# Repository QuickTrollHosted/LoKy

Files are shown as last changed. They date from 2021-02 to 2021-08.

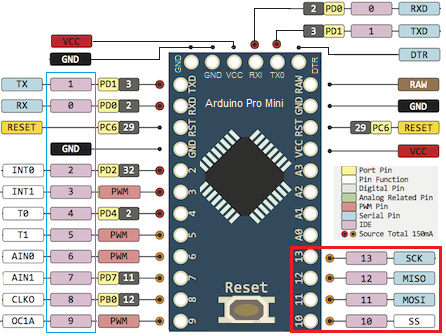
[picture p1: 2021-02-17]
LoKy_Documentation/Pin_Out/Pro_Mini.png

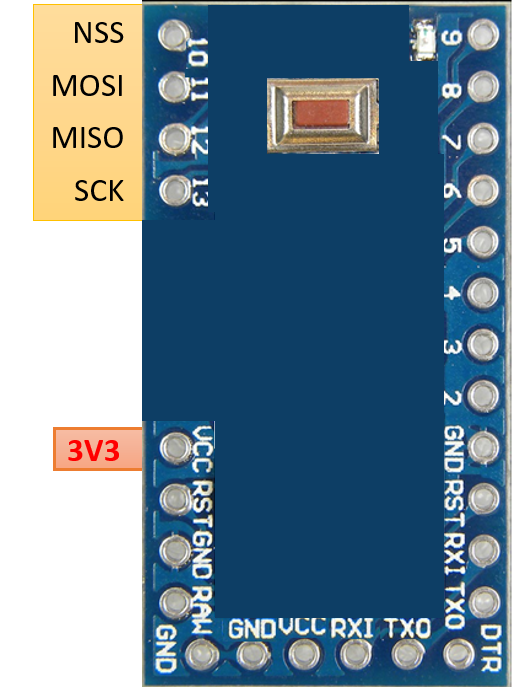
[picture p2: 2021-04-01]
LoKy_Documentation/Pin_Out/Pro_Mini_cut.png

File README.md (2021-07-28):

Shield: [][cc-by-nc-sa]

This work is licensed under a
[Creative Commons Attribution-NonCommercial-ShareAlike 4.0 International License][cc-by-nc-sa].

[][cc-by-nc-sa]

[cc-by-nc-sa]: http://creativecommons.org/licenses/by-nc-sa/4.0/
[cc-by-nc-sa-image]: https://licensebuttons.net/l/by-nc-sa/4.0/88x31.png
[cc-by-nc-sa-shield]: https://img.shields.io/badge/License-CC%20BY--NC--SA%204.0-lightgrey.svg

# LoKy

- LoKy is an Open-source project which creates a LoRaWAN end-device to connect with Linky meter in France. 
- The most recent firmware is V4

This End-device was created by Ferrari Jérôme and Ho Vu Duy Bao for CNRS/UGA/G-INP – G2ELAB

CNRS-logo
G2elab-logo
UGA-logo
GINP-logo

[GINP-logo]: https://www.grenoble-inp.fr/uas/alias1/LOGO/Grenoble+INP+-+%C3%89tablissement+%28couleur%2C+RVB%2C+120px%29.png
[CNRS-logo]: https://www.cnrs.fr/themes/custom/cnrs/logo.svg
[G2elab-logo]: https://g2elab.grenoble-inp.fr/uas/alias31/LOGO/G2Elab-logo.jpg
[UGA-logo]:https://encrypted-tbn0.gstatic.com/images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

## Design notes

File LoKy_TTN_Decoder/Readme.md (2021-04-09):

# LoKy_LPP Introduction

LoKyLPP is a payload format modified by HO Vu Duy Bao from IoT platform [Cayenne](https://mydevices.com/cayenne/features/).
It is used to send electrical data in a packed format to [The Things Network](https://www.thethingsnetwork.org).

## Dependencies
When using the decoder, you must install the [ArduinoJson 6.X](https://arduinojson.org/) library. You can find it in both the Arduino IDE and PlatformIO library managers.

## References
* [Cayenne Low Power Payload](https://mydevices.com/cayenne/docs/#lora-cayenne-low-power-payload)
* [IPSO data types](http://openmobilealliance.org/wp/OMNA/LwM2M/LwM2MRegistry.html#extlabel)

## License
Based in the work of [Johan Stokking](https://github.com/TheThingsNetwork/arduino-device-lib).
The MIT License (MIT)

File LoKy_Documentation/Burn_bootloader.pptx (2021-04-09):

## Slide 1

PART 1 - The prepare schematic
Voltage supply is 3,3 volts. This supply has to be well regulated with no voltage spikes and an extra 10uF capacitor between 3V3 and GND. Also, the reset pin is negative enabled. In order to disable it, we need to apply 3V3 to it.
To reset, a 10k Ohms resistor is needed between RESET and Vcc.
In this tutorial, ATMega328P works at 3V3. For that, between pins 9 and 10 we place a 8MHz crystal. But this crystal, in order to oscillate needs two capacitors of 22pF connected to GND. In the figure above, you have all the pins of the chip. Right now, if the microcontroller has a bootloader, we could upload a code. But let's imagine it doesn't have a bootloader.

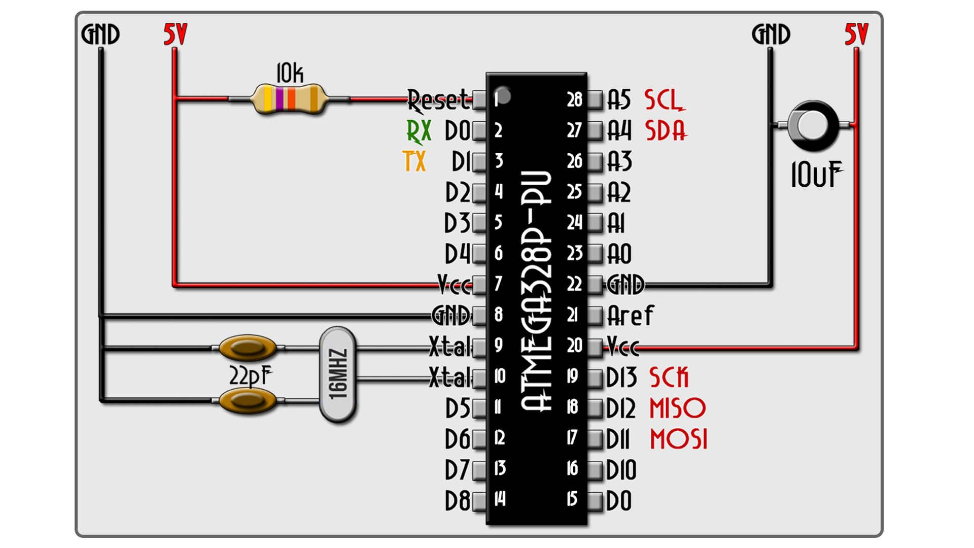
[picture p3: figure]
arduino on breadboard schematic

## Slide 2

PART 2 - Burn Bootloader
Now, if the chip doesn't have the bootloader (brand new chip), you have to make next connections from an Arduino ProMini. These are the SPI pins, CLOCK, MISO and MOSI.
Now connect the Arduino to your PC. Open Arduino IDE and go to File → Examples → Arduino ISP and upload that example. It’s time to burn the bootloader. Go to Tools → Programmer → Arduino as ISP. By that we change the programmer to ISP. Finally, go to Tools → Burn bootloader. Now the LEDs of the Arduino will blink a lot. Once you get the message of bootloader burned we are good to go.

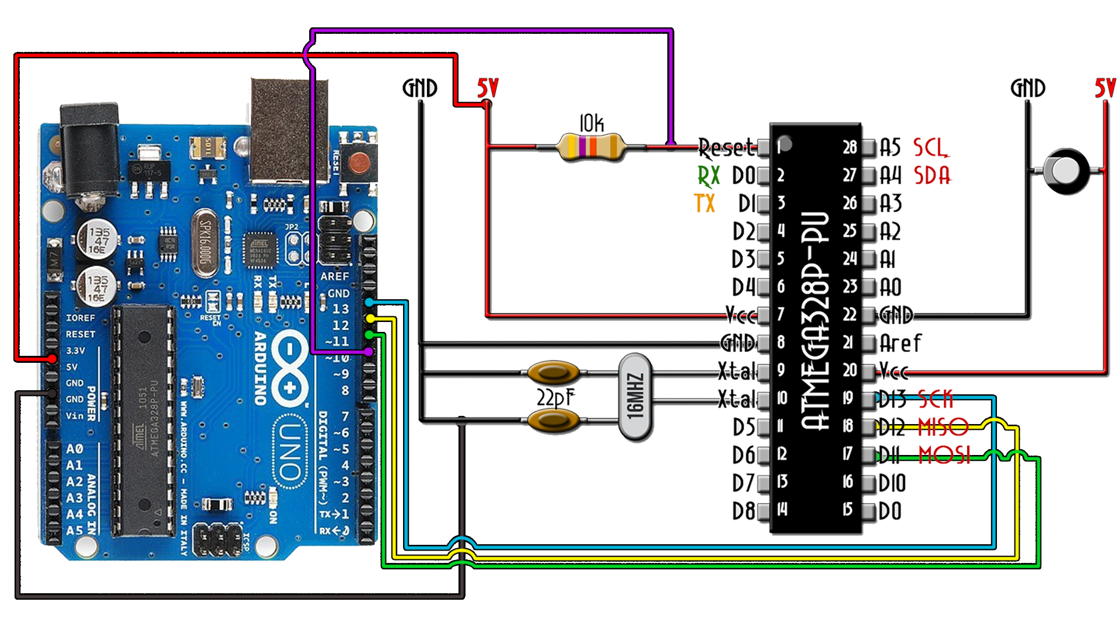
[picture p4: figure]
arduino on breadboard schematic

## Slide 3

PART 3 - Upload a code
Now, we have the bootloader so we can communicate with the RX and TX pins and upload a code. For that we need and FTDI module. Make the next connections and upload your code.

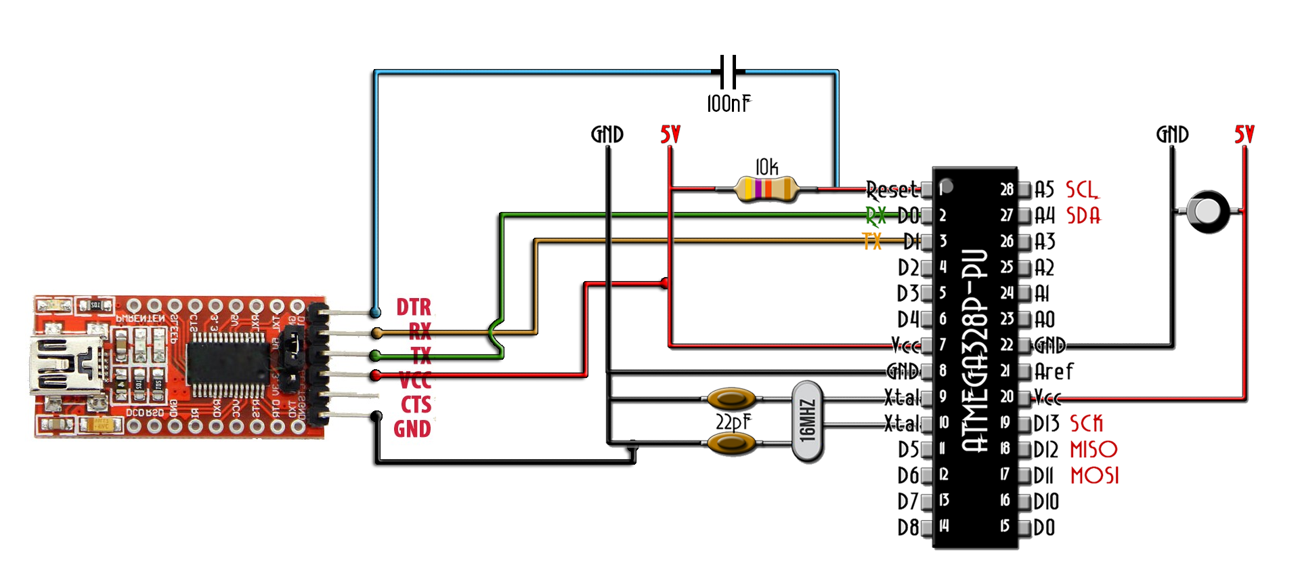
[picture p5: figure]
ATMega328 FTDI

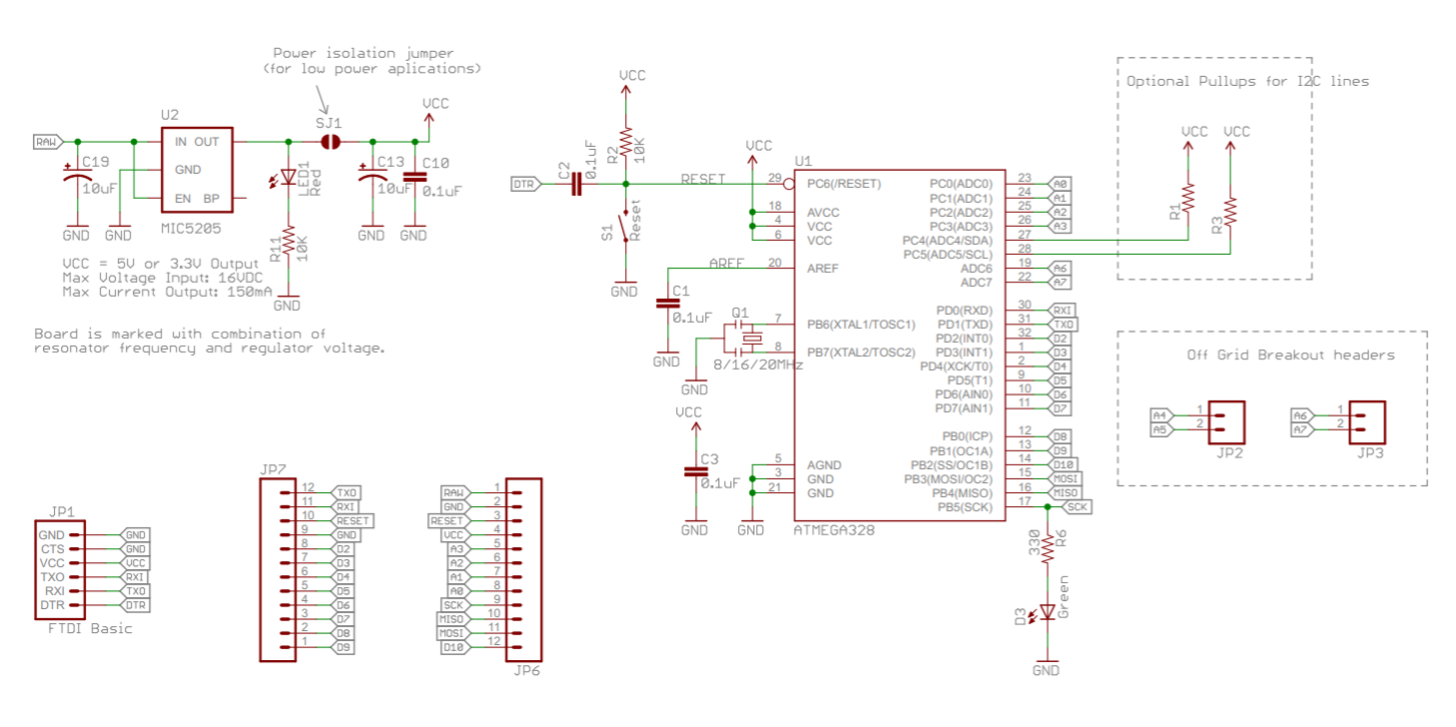
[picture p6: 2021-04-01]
LoKy_Documentation/Pin_Out/Schematic-Pro-Mini.PNG

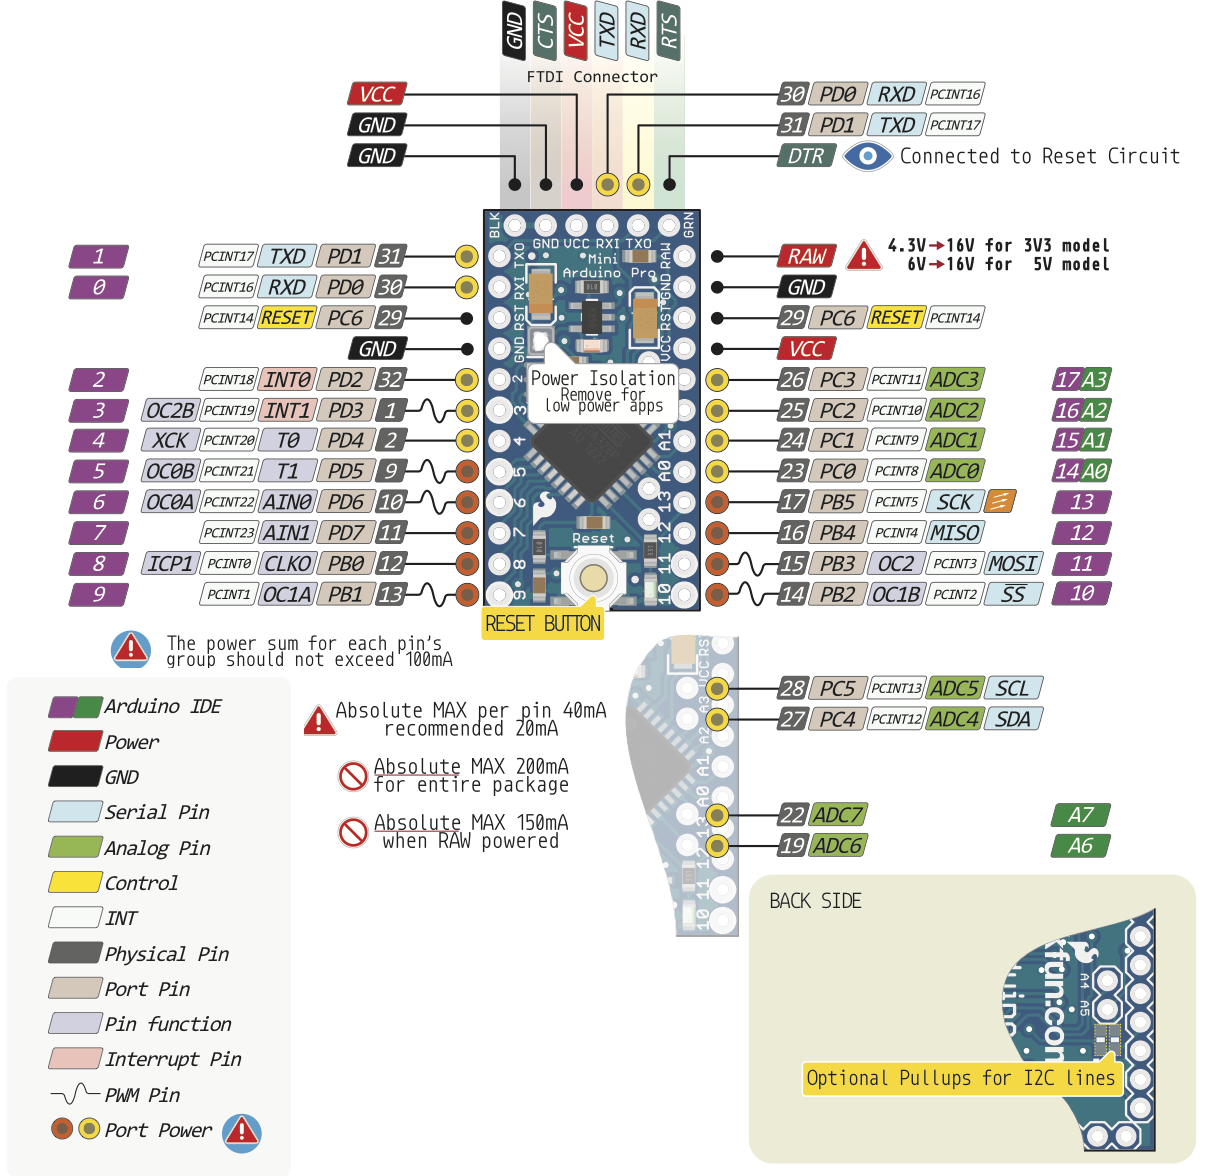
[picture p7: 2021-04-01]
LoKy_Documentation/Pin_Out/ProMini-full.png

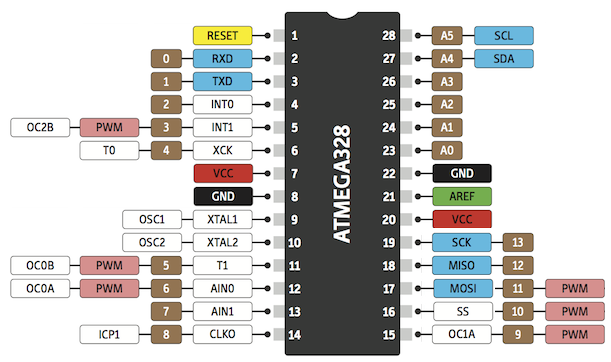
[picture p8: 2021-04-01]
LoKy_Documentation/Pin_Out/ATMEGA328P-PU.png

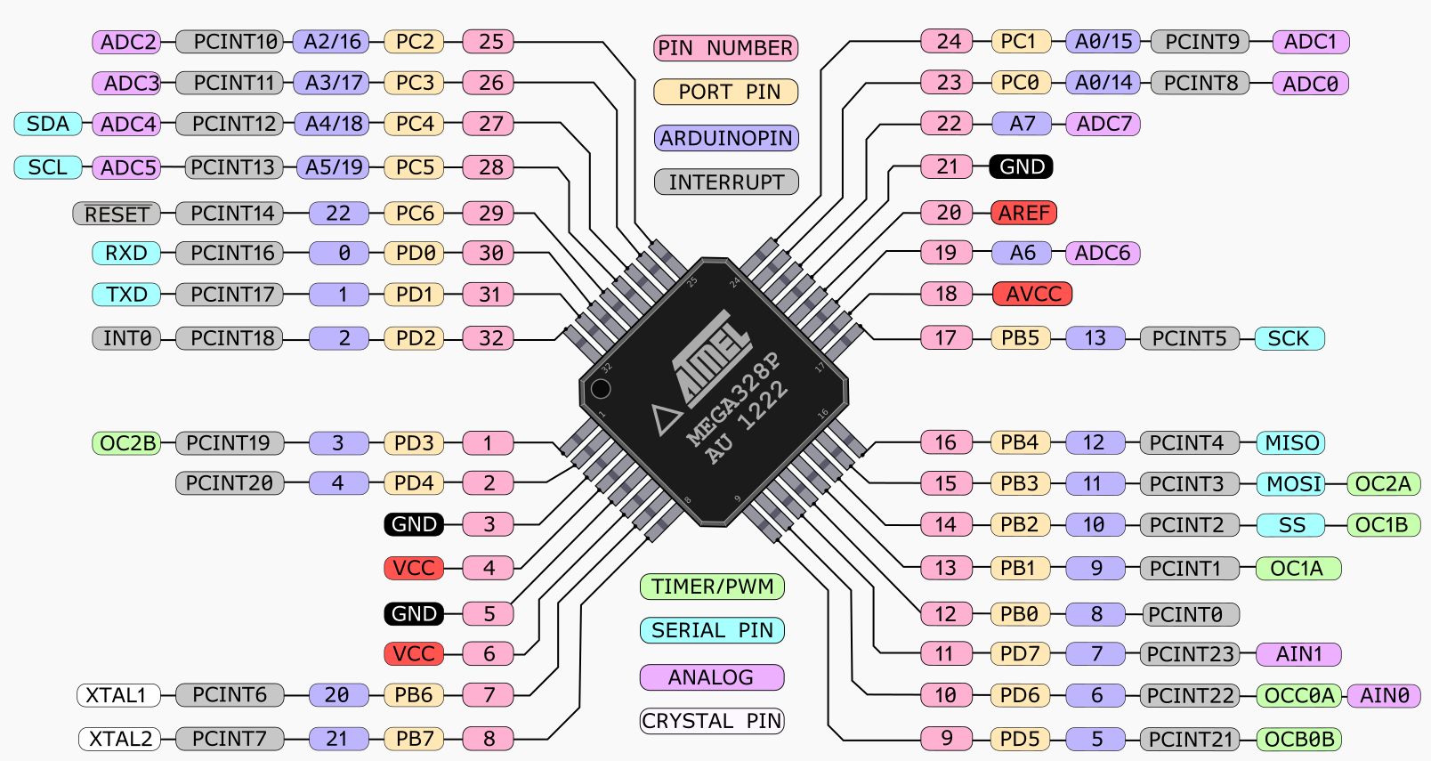
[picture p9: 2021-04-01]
LoKy_Documentation/Pin_Out/ATMEGA328P-AU.png

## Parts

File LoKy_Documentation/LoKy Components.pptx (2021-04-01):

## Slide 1

- Rectifier
- Regulator
- SuperCap

- Optocoupler

Power (pin A)

Antenna

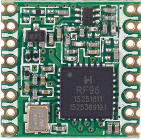
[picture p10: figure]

Common (pin I1)

LoKy

Hardware

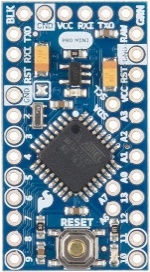
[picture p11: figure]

Decoder (pin I2)

Firmware

Info_TIC

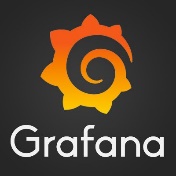
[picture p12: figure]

Application Server

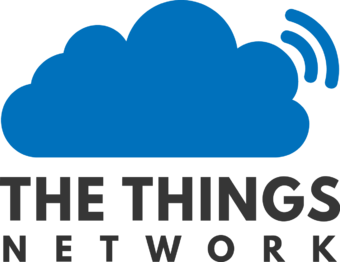
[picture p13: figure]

Node-RED

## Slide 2

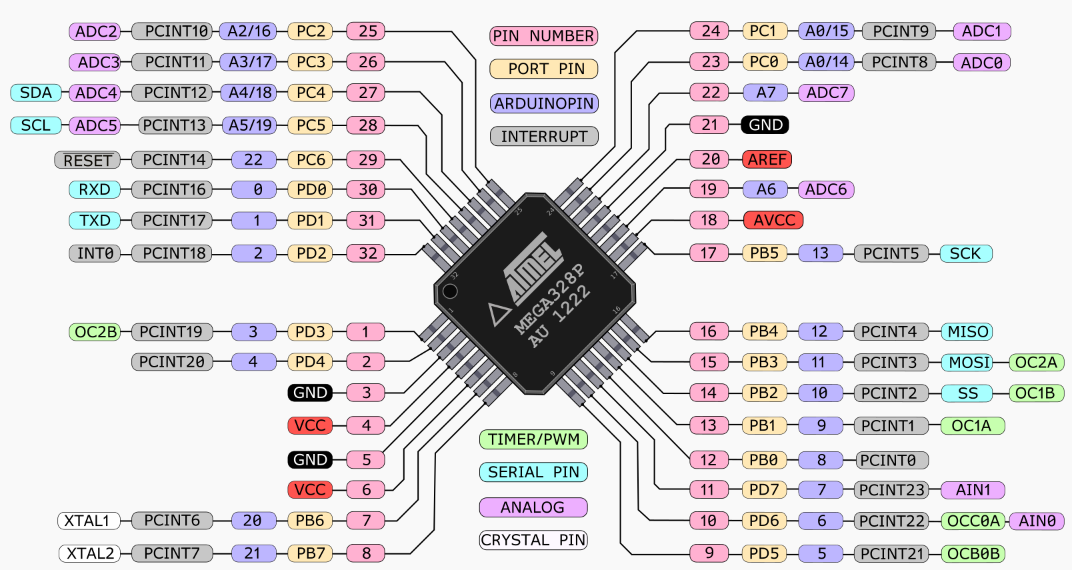
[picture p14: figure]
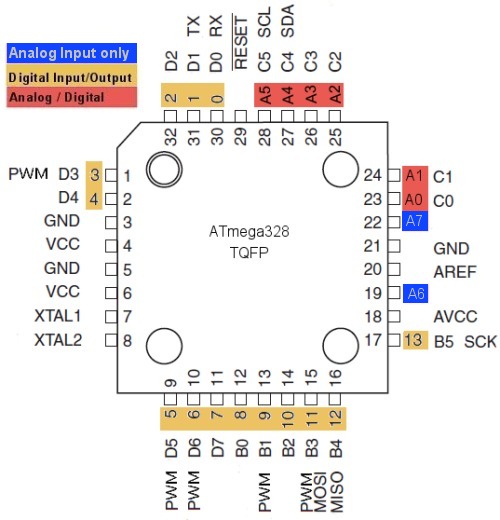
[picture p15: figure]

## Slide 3

NSS
MOSI
MISO
SCK

3V3

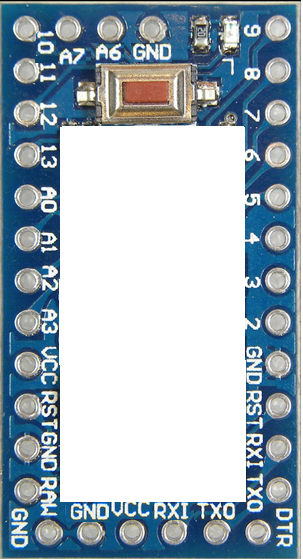
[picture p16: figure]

DIO2

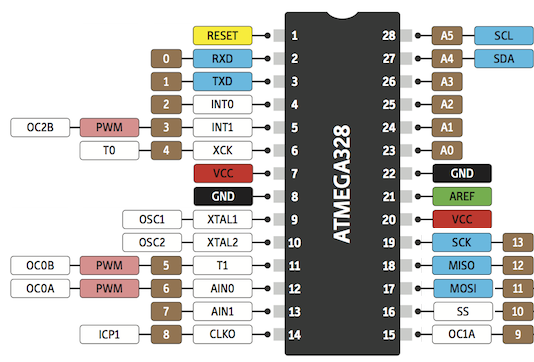
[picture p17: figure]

RST

DIO1


info_TIC

DIO0

GND


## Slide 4


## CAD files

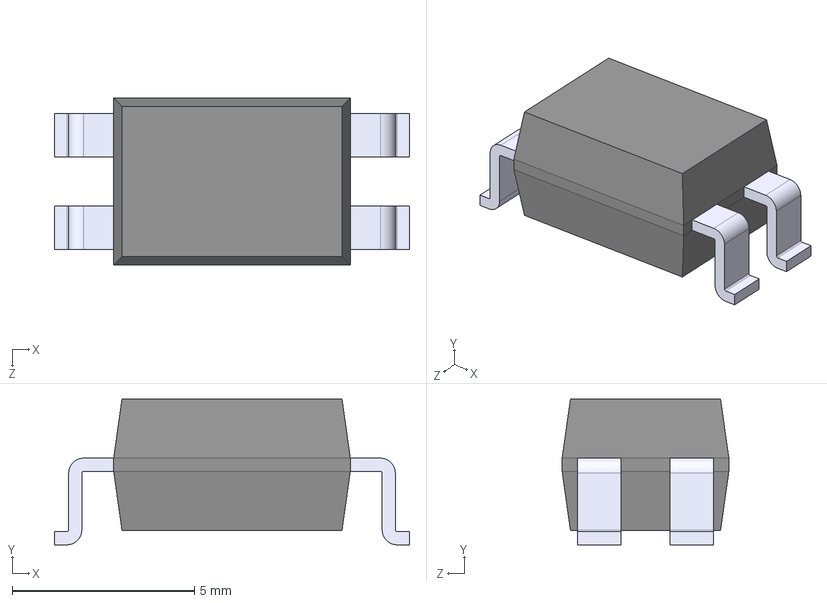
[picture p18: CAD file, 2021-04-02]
LoKy_PCB_Design/KiCAD-Lib/PC814/PC814.step
9.75 x 4.00 x 4.58 mm

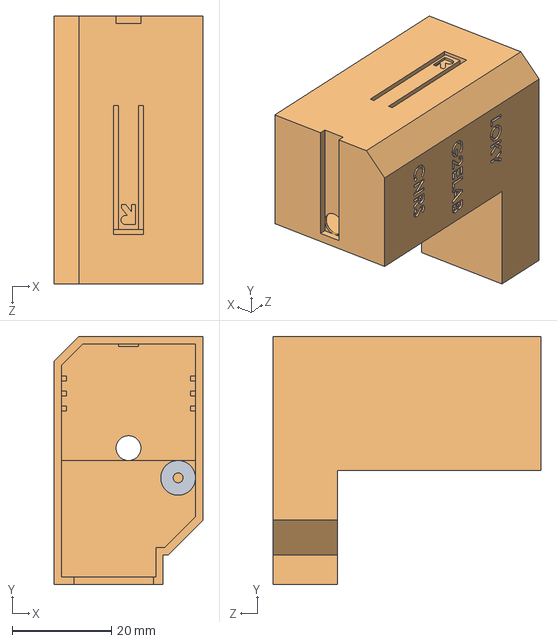
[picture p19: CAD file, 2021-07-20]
LoKy_STL_Boitier_3D/Loky_corps.STEP
30.0 x 50.0 x 54.0 mm

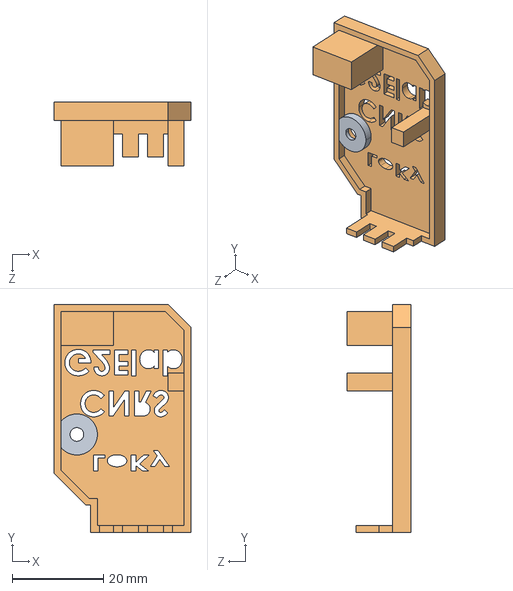
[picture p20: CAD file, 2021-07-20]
LoKy_STL_Boitier_3D/Loky_couvercle.STEP
30.0 x 50.0 x 14.0 mm

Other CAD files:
LoKy_STL_Boitier_3D/Loky_corps.STL
LoKy_STL_Boitier_3D/Loky_couvercle.STL

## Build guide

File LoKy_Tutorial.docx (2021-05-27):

# LoKy Tutorial

# 1. Arduino IDE:

## Setup board information:

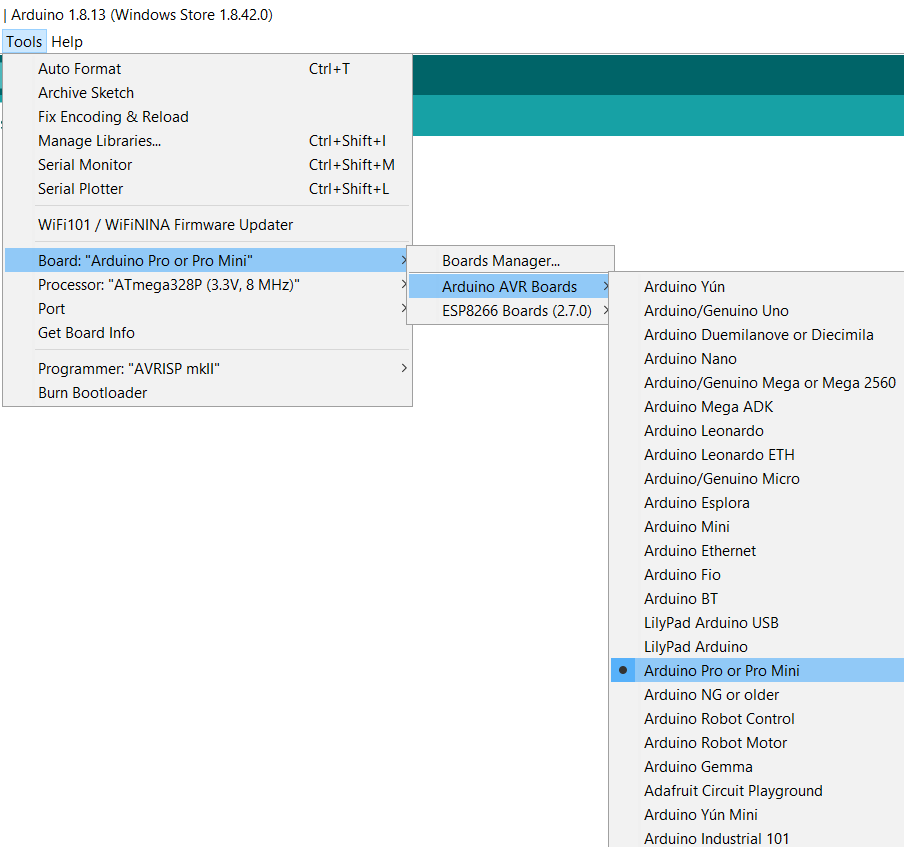
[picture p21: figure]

## Install version 1.6.21 on Boards Manager (the higher versions have bugs for LMiC library)

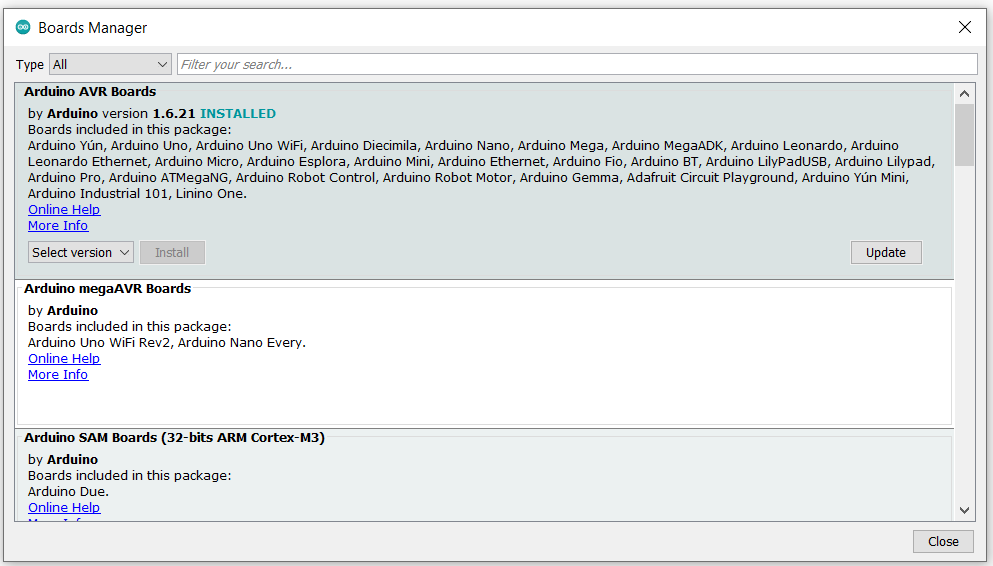
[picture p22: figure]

  - Select Processor: “ATmega328P (3.3V, 8MHz)” and Port that is connecting to ProMini
  - Install Libraries following this instruction: https://www.arduino.cc/en/guide/libraries

# 2. The Things Network (TTN)

a. Login to TTN console: https://console.thethingsnetwork.org/ and add a new Application

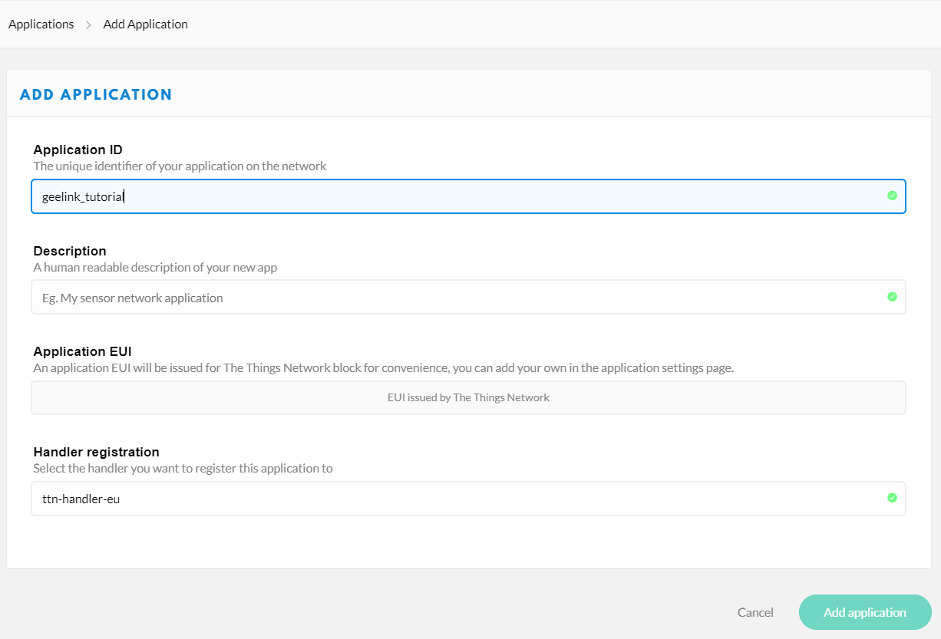
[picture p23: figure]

b. Device register

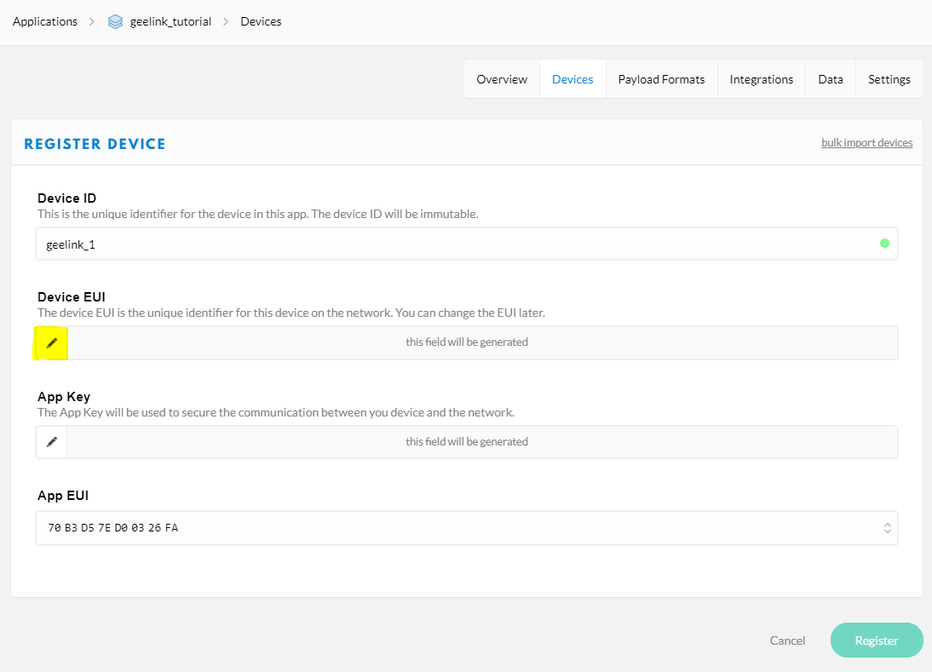
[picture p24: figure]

# c. After registering an OTAA device, adjust the keys into the following format

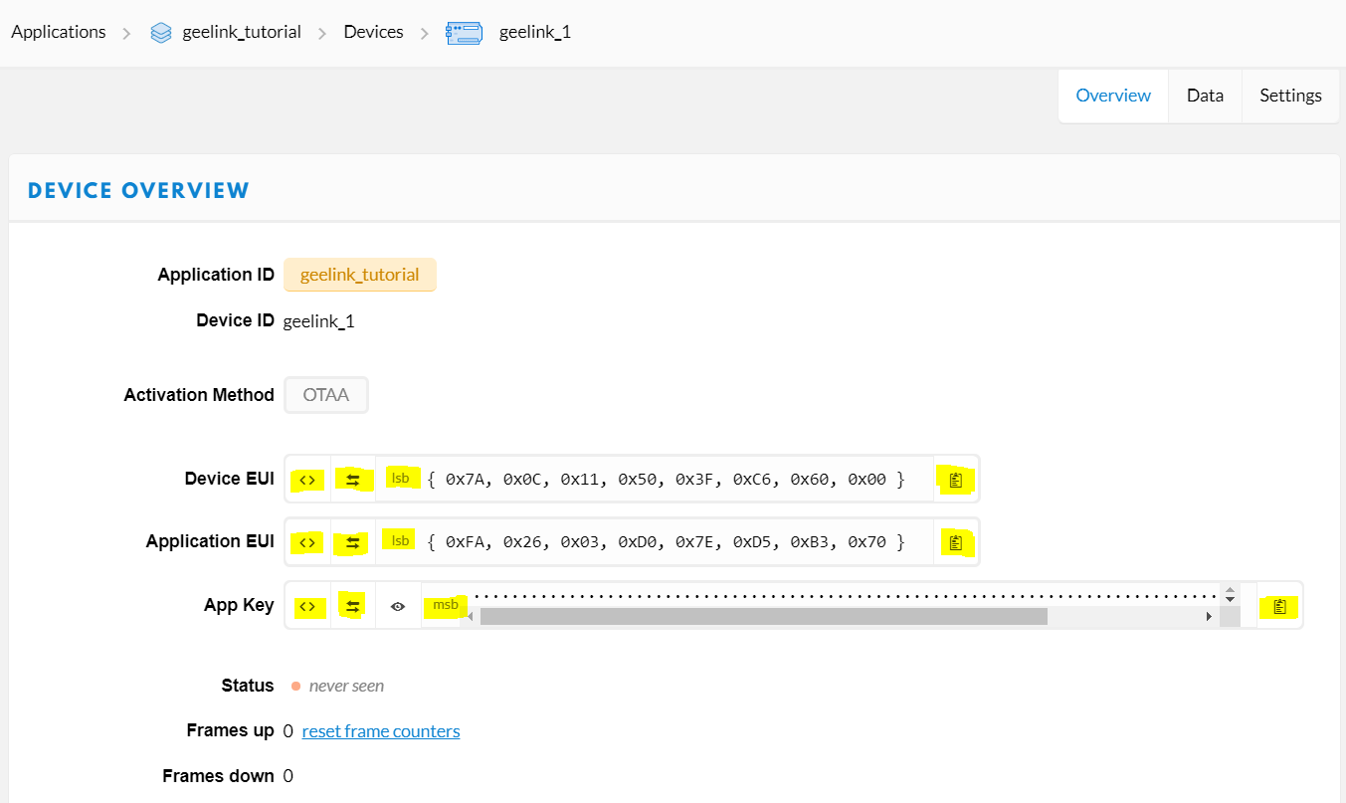
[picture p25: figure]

# 3. Payload decoder on TTN

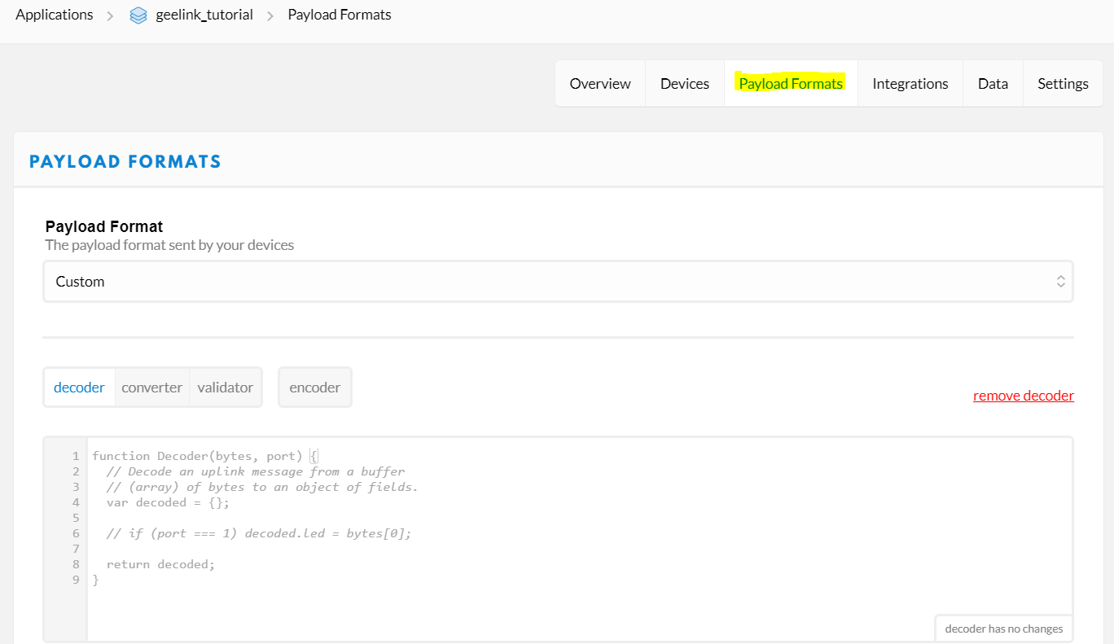
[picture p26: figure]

- Change the decoder to the LoKy_decoder and remember to SAVE before add integration

# 4. Integrations on TTN

- Add Data Storage integration:

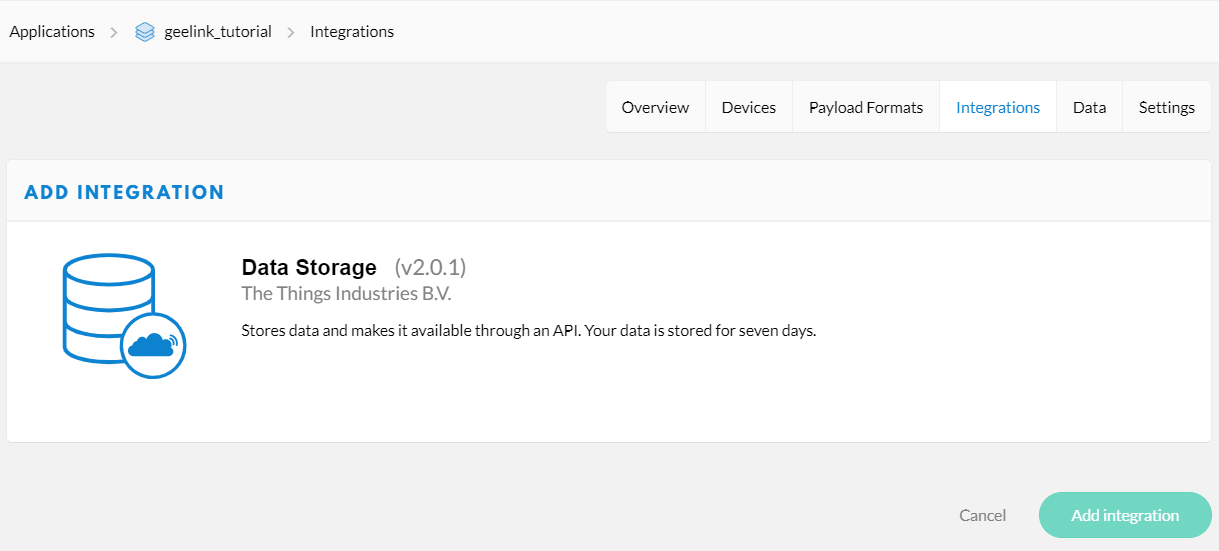
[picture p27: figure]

- Now, we have everything to run:

- LoKy main board

- Arduino and its stuff

- last but not least, TTN configured.

# 5. LoKy Firmware upload:

      - First we need to replace the keys (in section 2.c) from TTN in “3_Device_Keys.h”
      - Depending on the “option tarifaire” of Linky, we can use BASE or HCHP for our device by comment and uncomment line 11 or 12 of the main sketch.
      - Upload the sketch and check the operation of device from the Serial Monitor on Arduino IDE.
      - Finally, we can plug LoKy to the compteur and done!
- Section 6 is used for Application server and Database.

# 6. Application Server

- Install InfluxDB and Grafana following this instruction:

https://github.com/ITU-PITLab/public/blob/master/TheThingsNetwork%2Bnode-red%2Binfluxdb%2Bgrafana.md

- Install Node-RED

If Git is not installed on your PC: https://git-scm.com/downloads. After that, run this command on Gitbash sudo npm install -g --unsafe-perm node-red

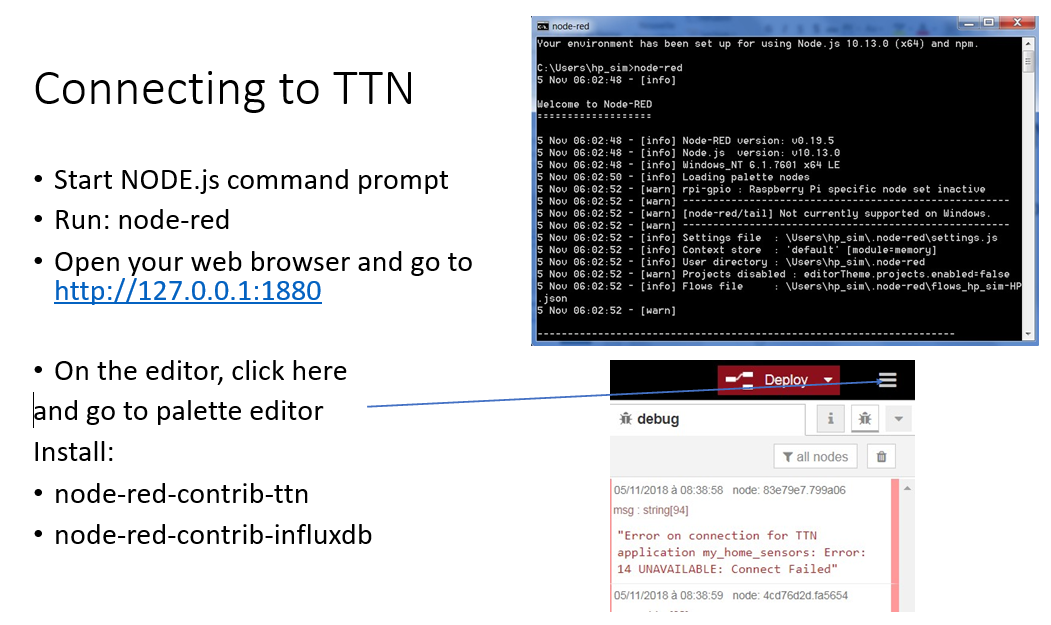
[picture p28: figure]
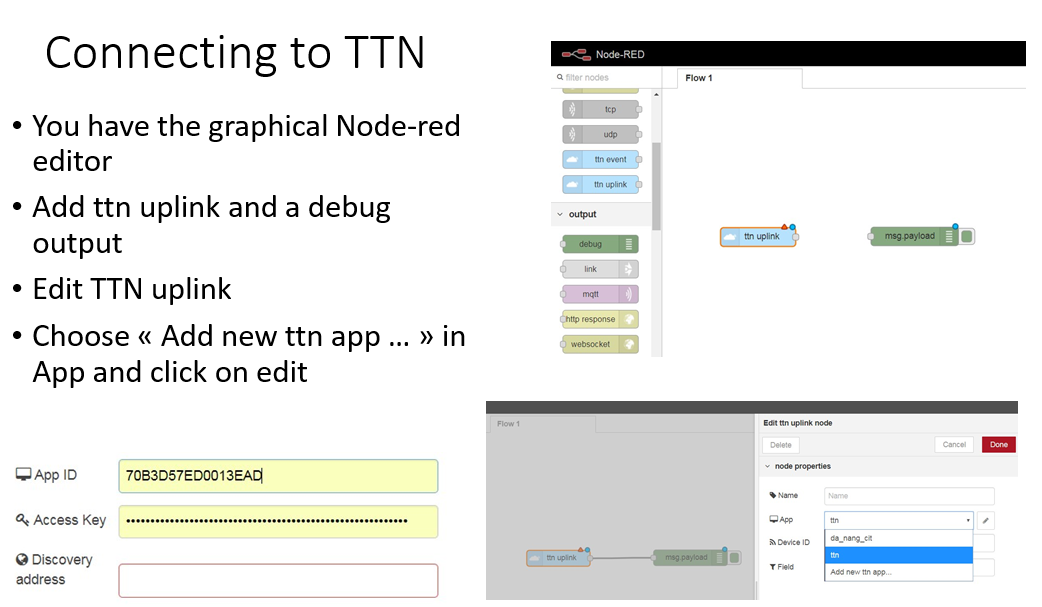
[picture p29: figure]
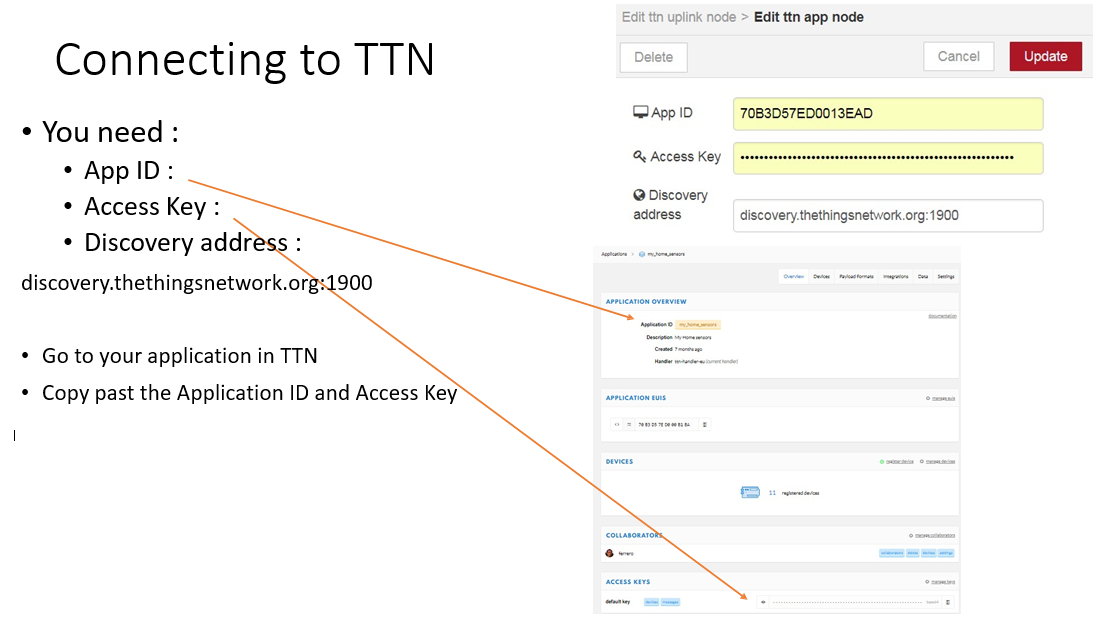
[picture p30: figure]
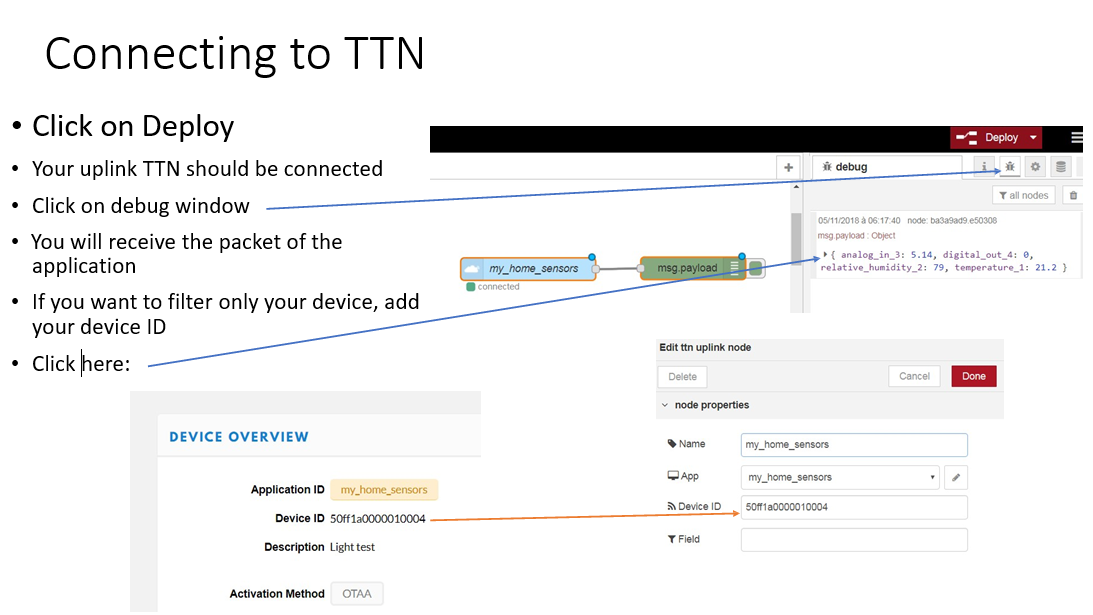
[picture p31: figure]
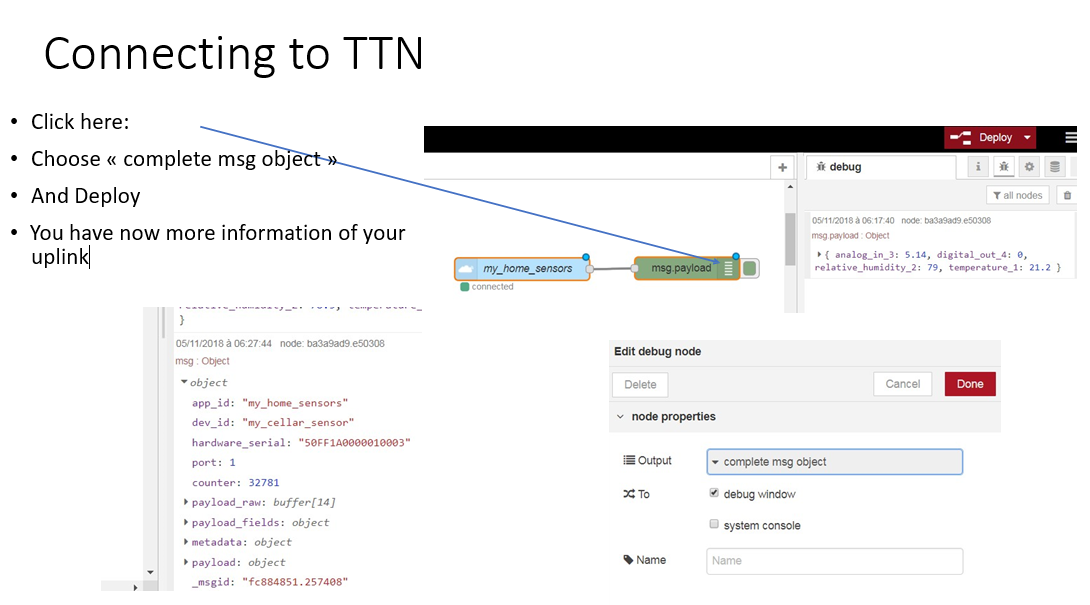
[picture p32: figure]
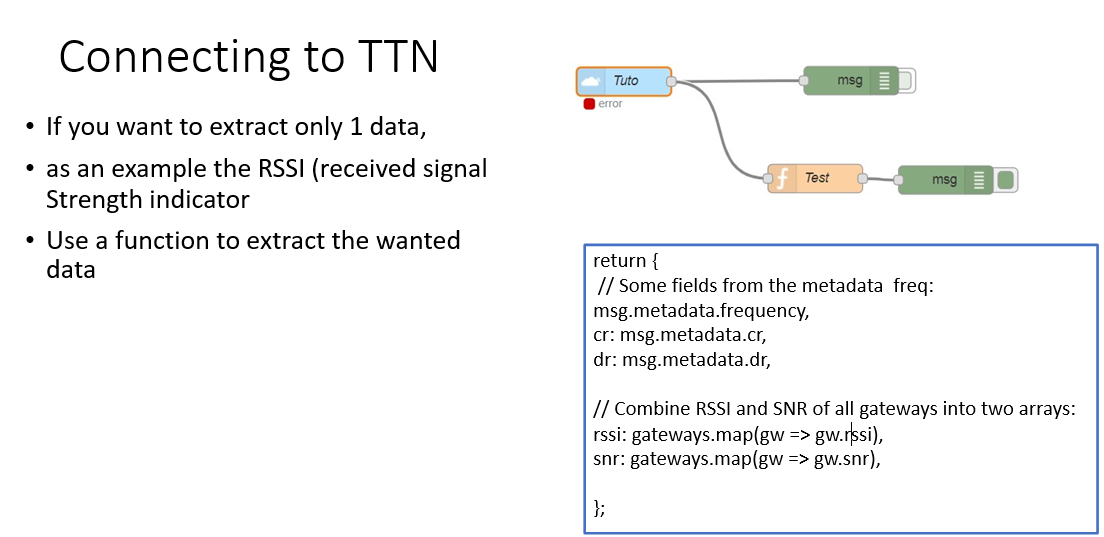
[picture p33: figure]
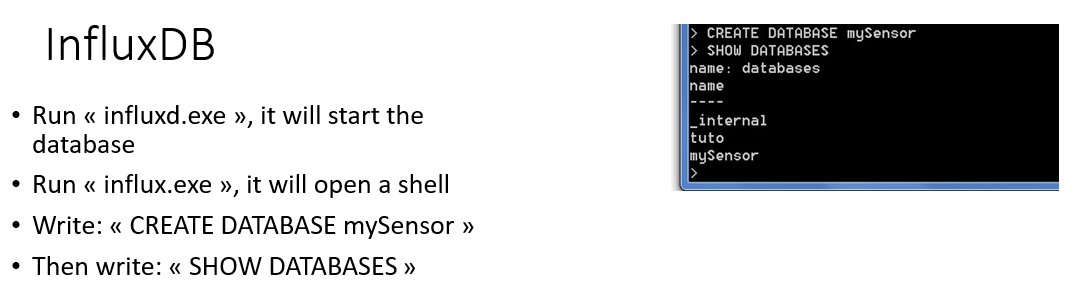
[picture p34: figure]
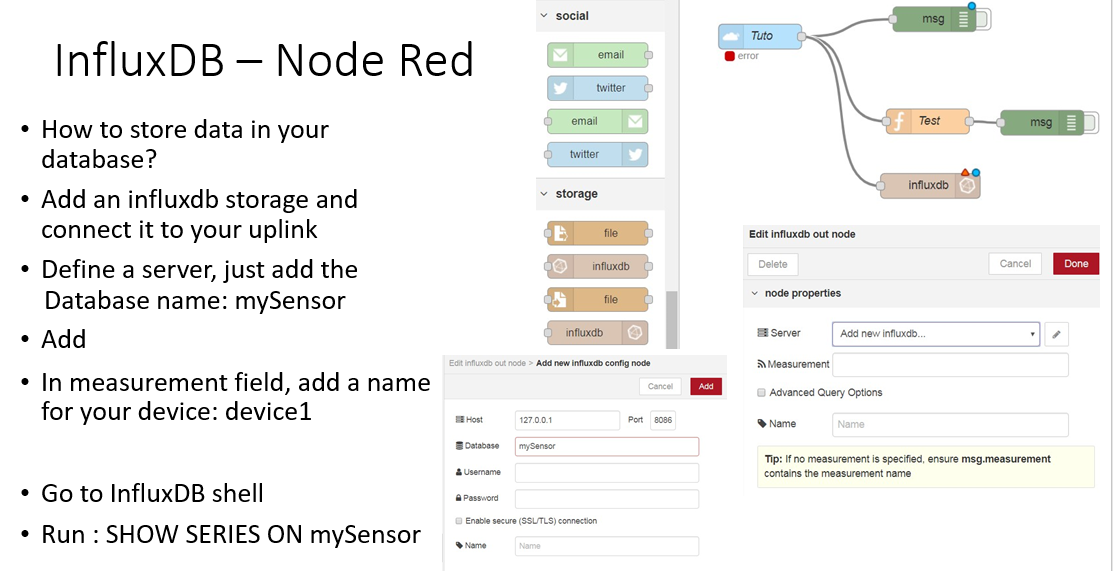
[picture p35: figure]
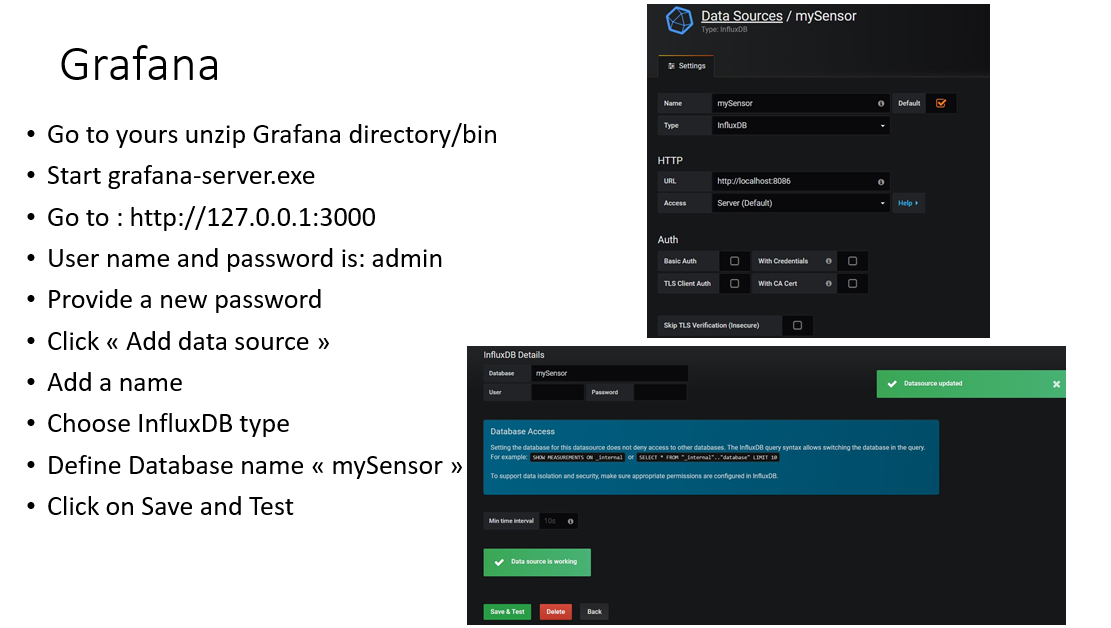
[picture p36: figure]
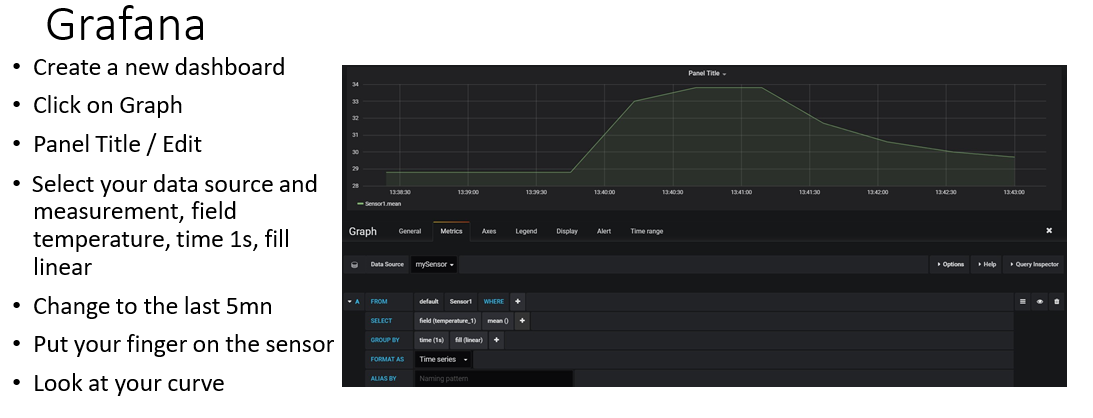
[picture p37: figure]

*Credit to GitHub: Fabien FERRERO – UCA board

LoKy – Linky with LoRaWAN - HO Vu Duy Bao 8

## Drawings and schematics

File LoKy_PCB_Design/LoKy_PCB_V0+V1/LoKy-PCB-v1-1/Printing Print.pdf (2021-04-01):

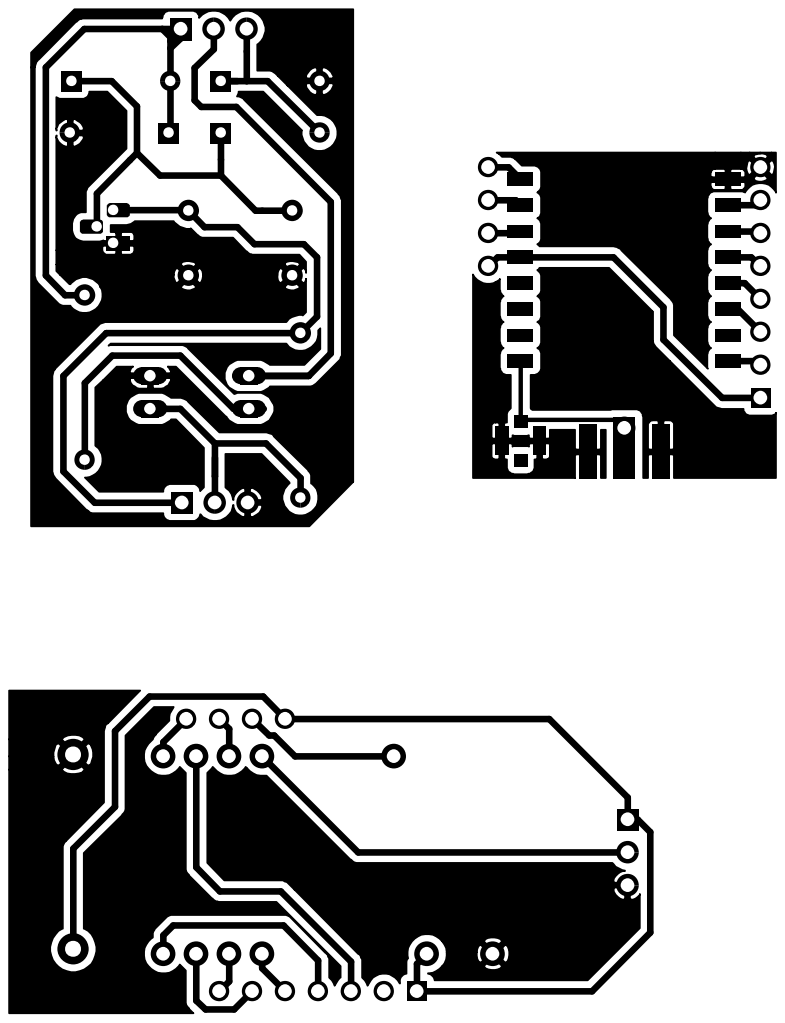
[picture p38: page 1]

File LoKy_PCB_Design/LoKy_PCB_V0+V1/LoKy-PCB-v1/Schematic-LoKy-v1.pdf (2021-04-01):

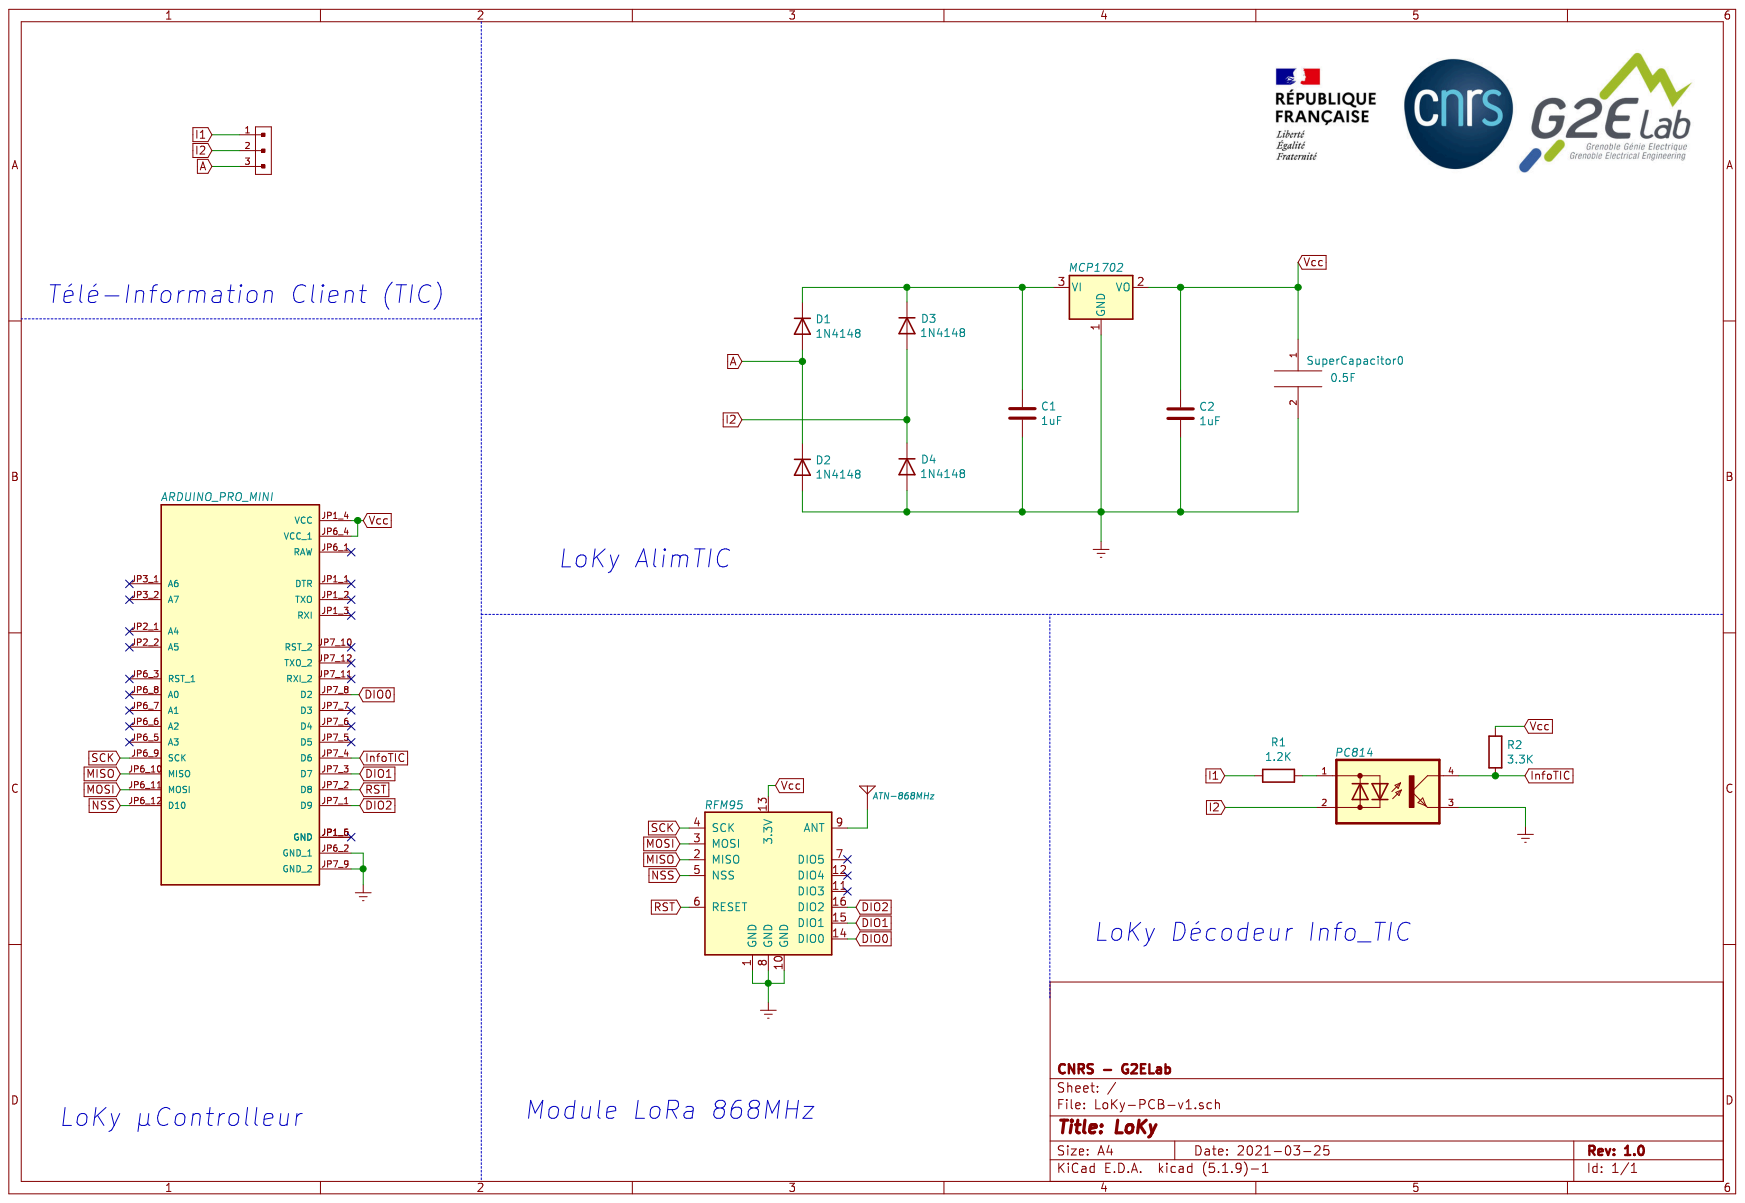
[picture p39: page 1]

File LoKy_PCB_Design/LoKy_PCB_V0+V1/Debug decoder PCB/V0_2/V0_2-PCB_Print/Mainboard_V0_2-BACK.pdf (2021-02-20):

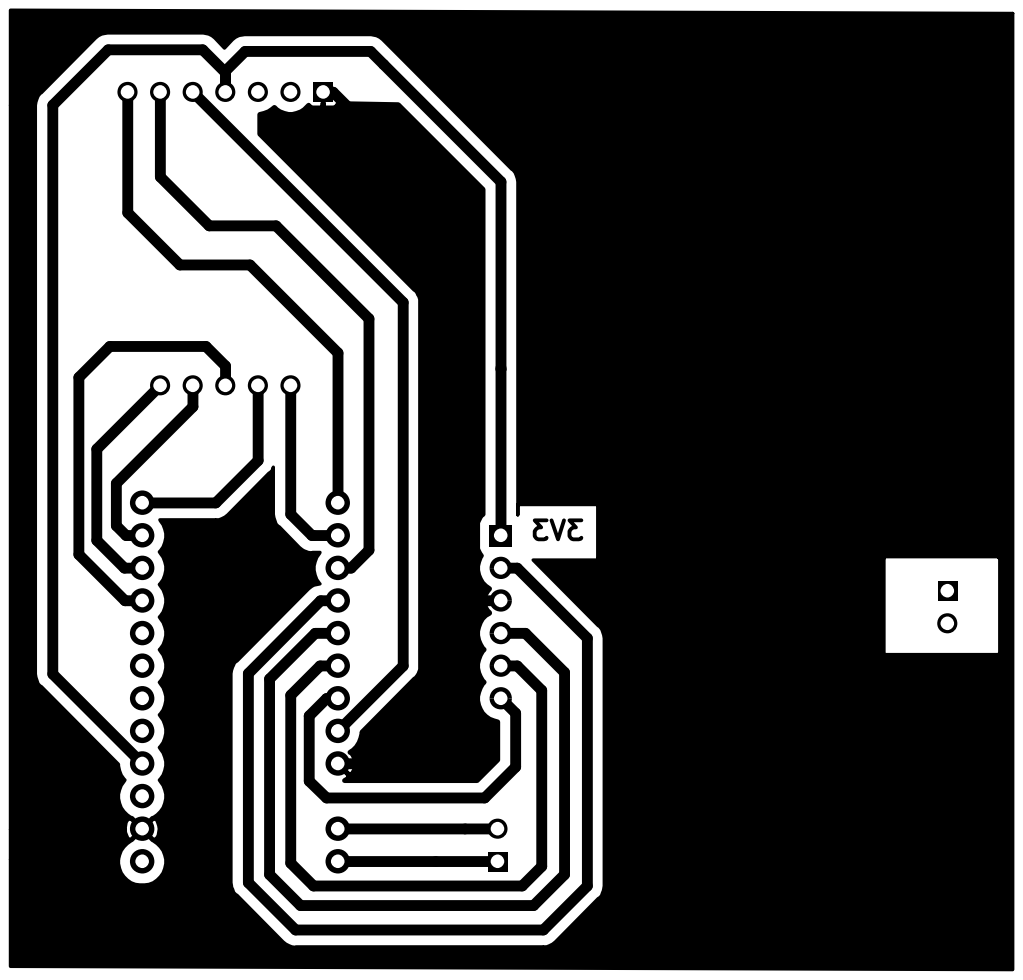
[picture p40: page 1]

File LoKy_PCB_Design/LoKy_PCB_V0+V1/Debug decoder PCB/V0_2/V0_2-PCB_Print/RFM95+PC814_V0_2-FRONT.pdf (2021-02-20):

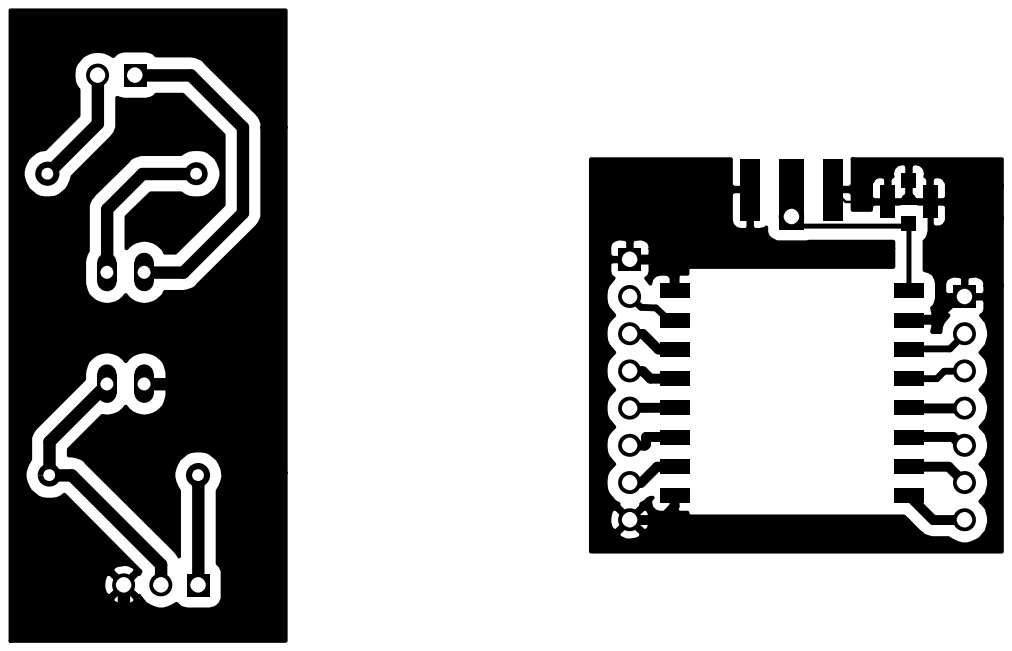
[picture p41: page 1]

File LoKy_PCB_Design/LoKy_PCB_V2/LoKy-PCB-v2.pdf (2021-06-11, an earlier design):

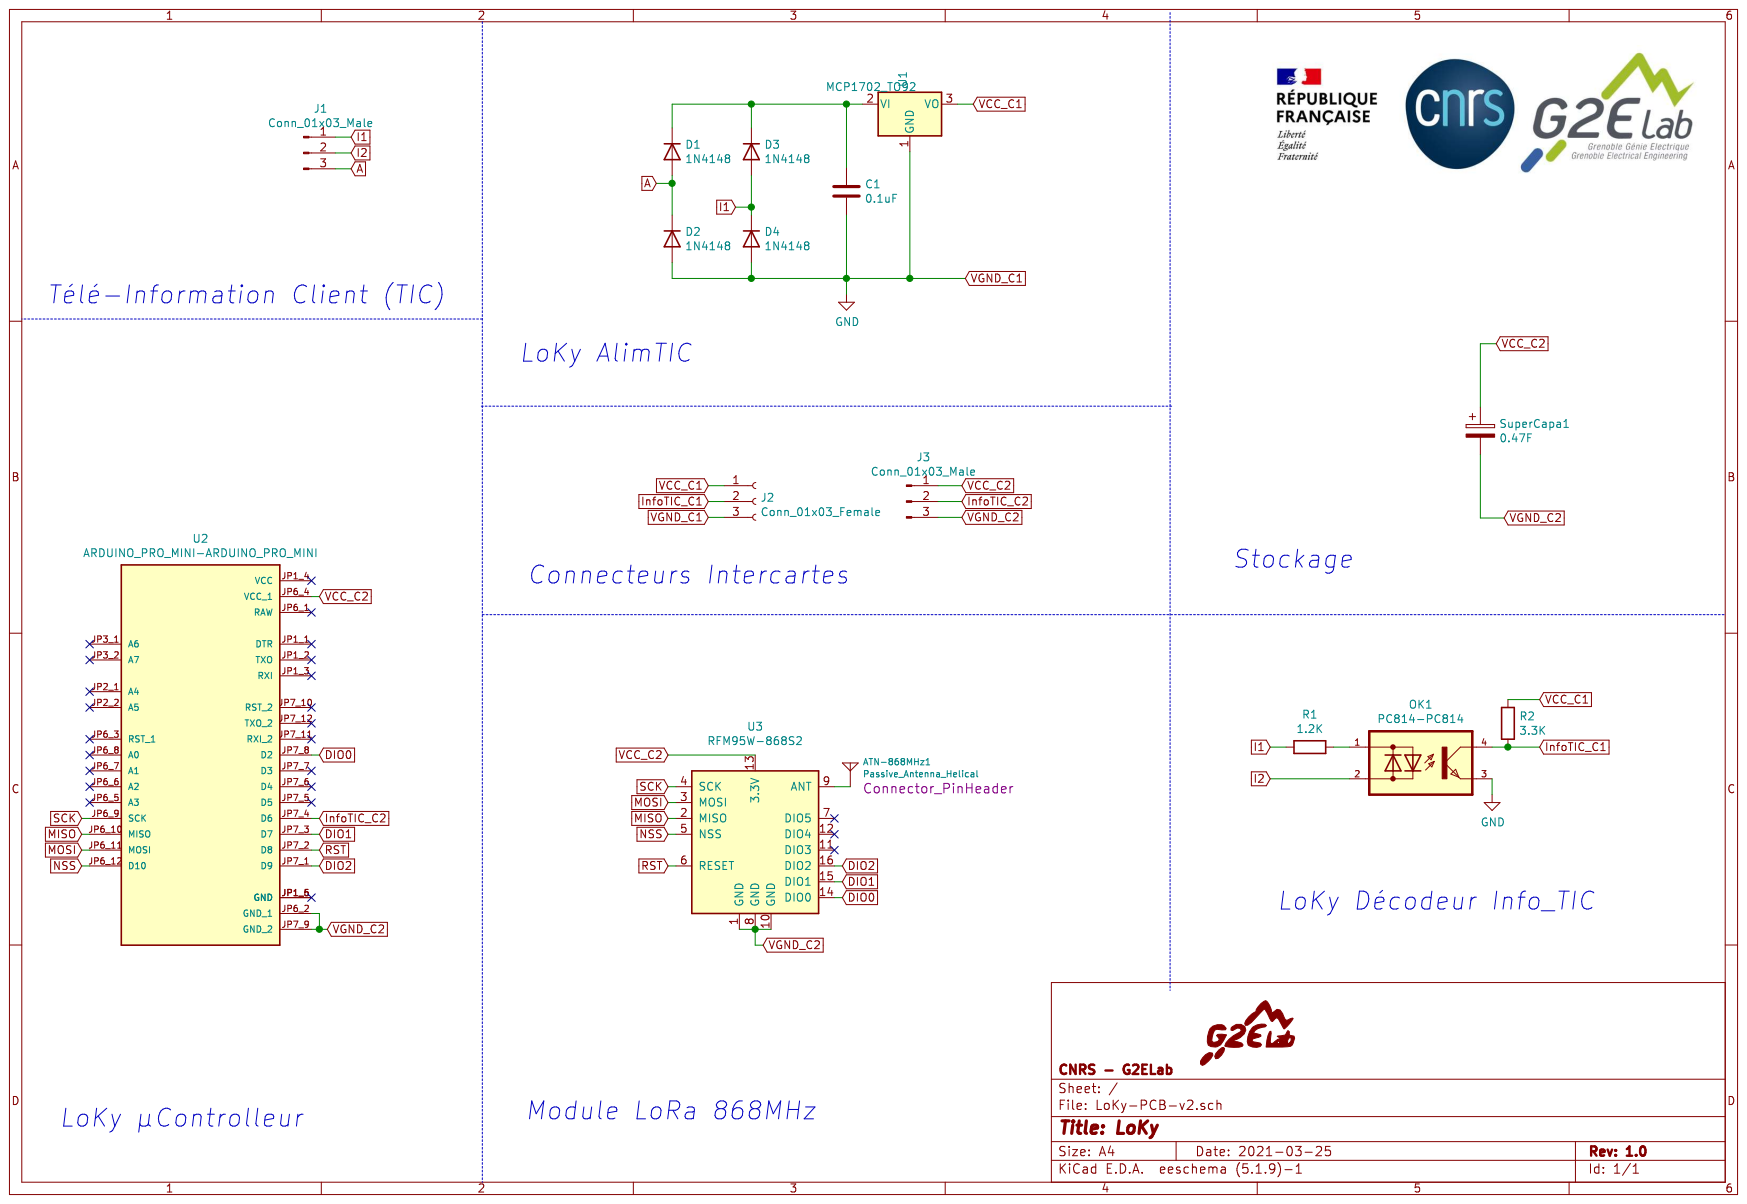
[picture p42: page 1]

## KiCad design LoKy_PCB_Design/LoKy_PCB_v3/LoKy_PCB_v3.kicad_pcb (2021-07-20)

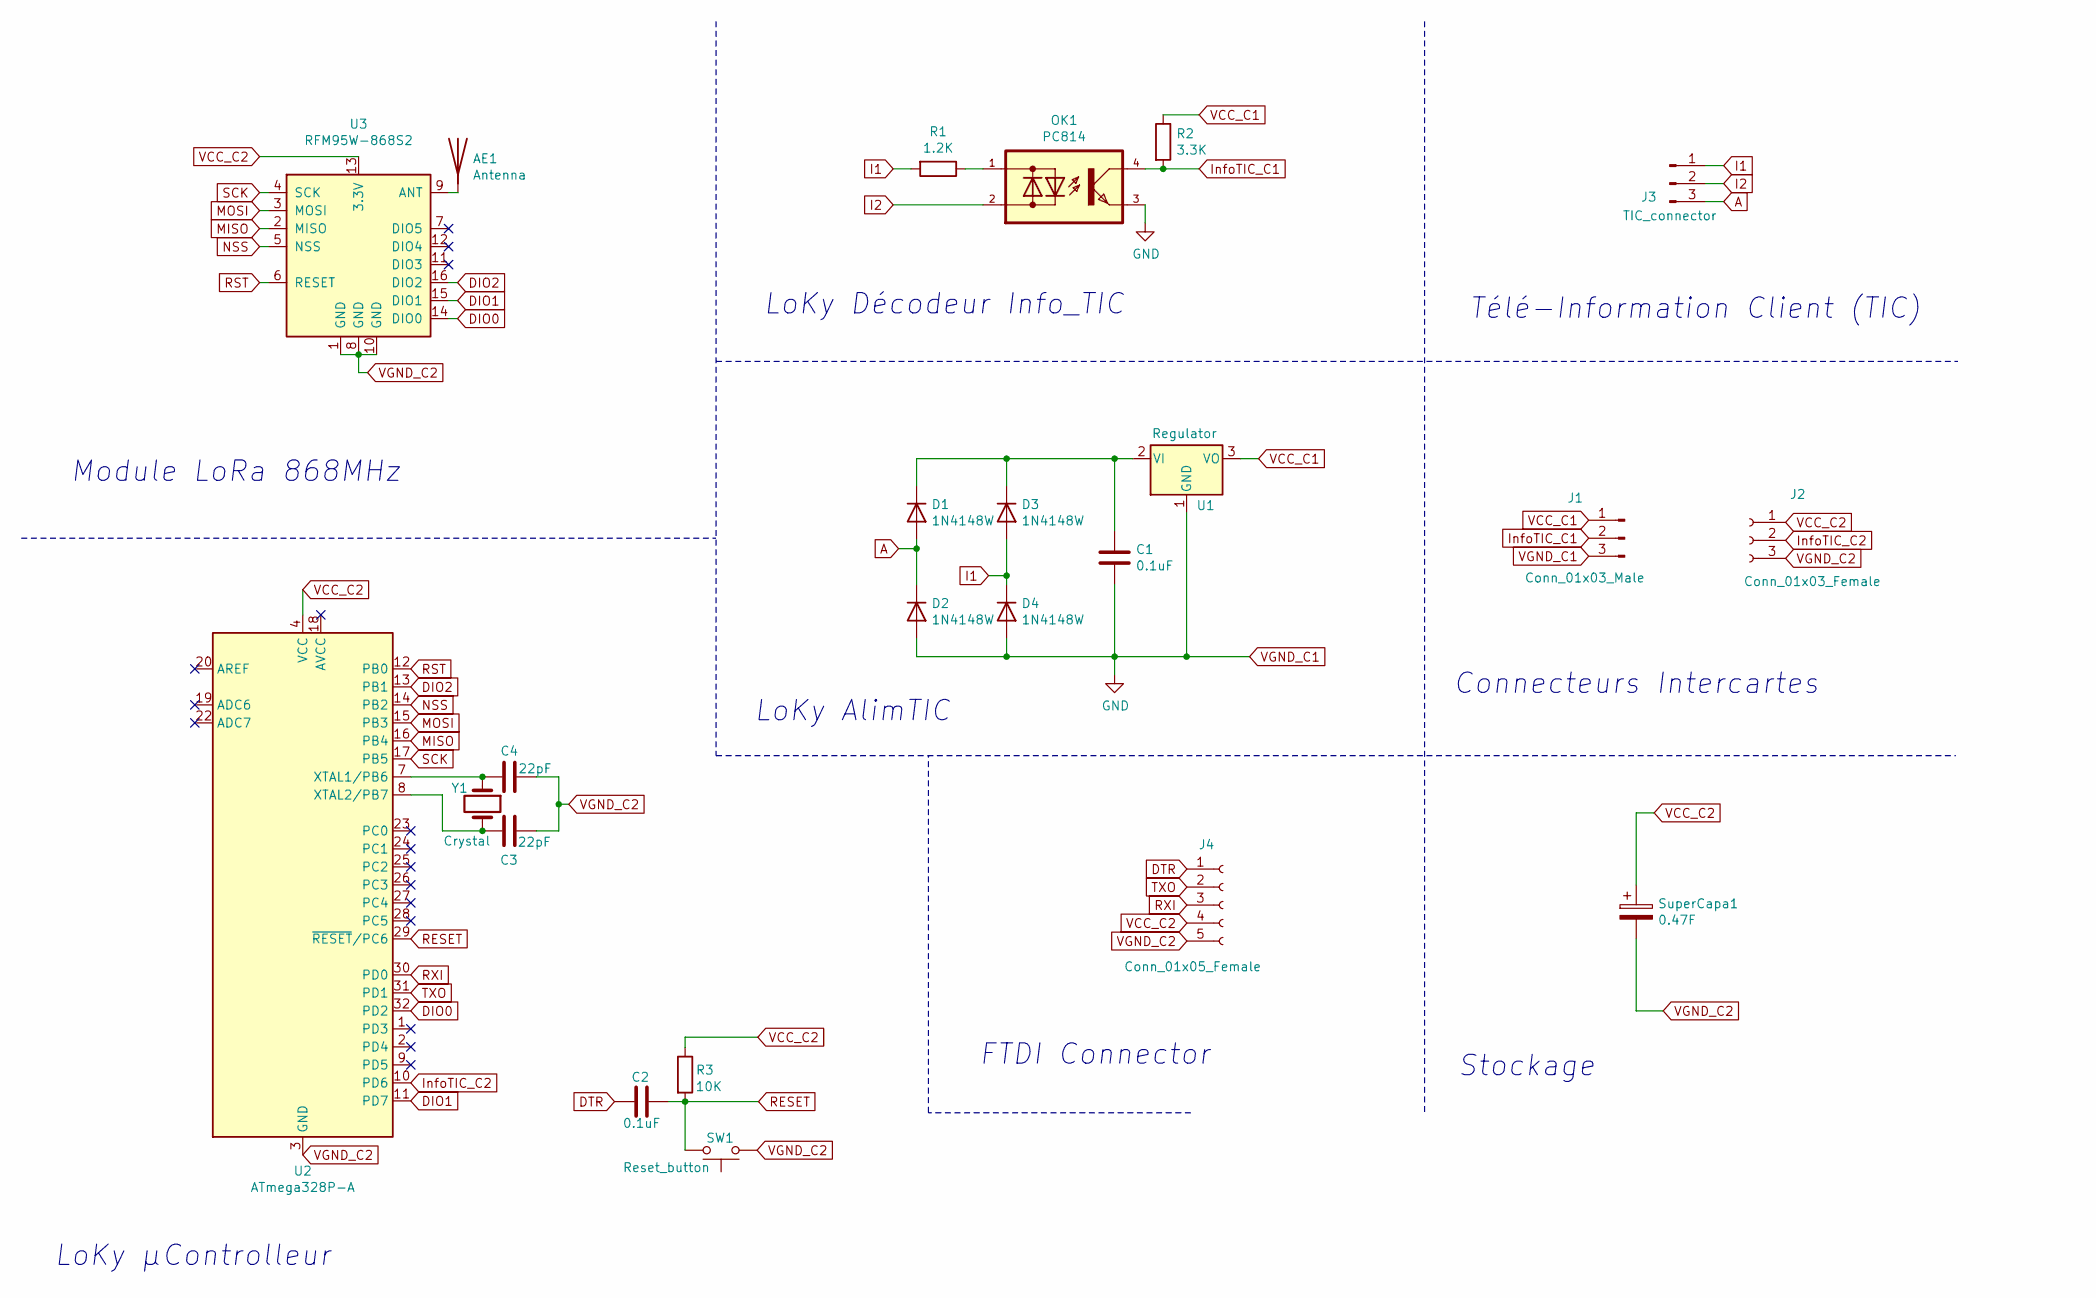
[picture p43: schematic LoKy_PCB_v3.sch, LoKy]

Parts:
AE1: Antenna; Texas_SWRA416_868MHz_915MHz
C1: 0.1uF; C_Rect_L7.2mm_W2.5mm_P5.00mm_FKS2_FKP2_MKS2_MKP2
C2: 0.1uF; C_Disc_D4.7mm_W2.5mm_P5.00mm
C3: 22pF; C_Disc_D4.7mm_W2.5mm_P5.00mm
C4: 22pF; C_Rect_L7.2mm_W2.5mm_P5.00mm_FKS2_FKP2_MKS2_MKP2
D1, D2, D3, D4: 1N4148W; D_T-1_P5.08mm_Horizontal
J1: Conn_01x03_Male; PinHeader_1x03_P2.54mm_Horizontal
J2: Conn_01x03_Female; PinSocket_1x03_P2.54mm_Vertical
J3: TIC_connector; Connecteur_Linky
J4: Conn_01x05_Female; PinSocket_1x05_P2.54mm_Vertical
OK1: PC814; DIL04
R1: 1.2K; R_Axial_DIN0207_L6.3mm_D2.5mm_P7.62mm_Horizontal
R2: 3.3K; R_Axial_DIN0207_L6.3mm_D2.5mm_P7.62mm_Horizontal
R3: 10K; R_Axial_DIN0207_L6.3mm_D2.5mm_P7.62mm_Horizontal
SW1: Reset_button; SW_SPST_FSMSM
SuperCapa1: 0.47F; SuperCapa
U1: Regulator; TO-92_Inline
U2: ATmega328P-A; TQFP-32_7x7mm_P0.8mm
U3: RFM95W-868S2; HOPERF_RFM9XW_SMD
Y1: Crystal; Crystal_SMD_HC49-SD

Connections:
A: D1.2 (A), D2.1 (K), J3.3
DIO0: U2.32 (PD2), U3.14 (DIO0)
DIO1: U2.11 (PD7), U3.15 (DIO1)
DIO2: U2.13 (PB1), U3.16 (DIO2)
DTR: C2.1, J4.1
I1: D3.2 (A), D4.1 (K), J3.1, R1.2
I2: J3.2, OK1.2
InfoTIC_C1: J1.2, OK1.4, R2.2
InfoTIC_C2: J2.2, U2.10 (PD6)
MISO: U2.16 (PB4), U3.2 (MISO)
MOSI: U2.15 (PB3), U3.3 (MOSI)
NSS: U2.14 (PB2), U3.5 (NSS)
unnamed: AE1.1, U3.9 (ANT)
unnamed: C1.1, D1.1 (K), D3.1 (K), U1.2 (VI)
unnamed: C3.1, U2.8 (XTAL2/PB7), Y1.2
unnamed: C4.1, U2.7 (XTAL1/PB6), Y1.1
unnamed: OK1.1, R1.1
RESET: C2.2, R3.2, SW1.1, U2.29 (~RESET~/PC6)
RST: U2.12 (PB0), U3.6 (RESET)
RXI: J4.3, U2.30 (PD0)
SCK: U2.17 (PB5), U3.4 (SCK)
TXO: J4.2, U2.31 (PD1)
VCC_C1: J1.1, R2.1, U1.3 (VO)
VCC_C2: J2.1, J4.4, R3.1, SuperCapa1.1, U2.4 (VCC), U2.6 (VCC), U3.13 (3.3V)
VGND_C1: C1.2, D2.2 (A), D4.2 (A), J1.3, OK1.3, U1.1 (GND)
VGND_C2: C3.2, C4.2, J2.3, J4.5, SW1.2, SuperCapa1.2, U2.3 (GND), U2.5 (GND), U2.21 (GND), U3.1 (GND), U3.8 (GND), U3.10 (GND)

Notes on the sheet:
LoKy μControlleur
Module LoRa 868MHz
LoKy AlimTIC
LoKy Décodeur Info_TIC
Télé-Information Client (TIC)
Connecteurs Intercartes
Stockage
FTDI Connector

Board: 2 copper layers, 22 parts (0 on the bottom side), 25 nets, no tracks yet.

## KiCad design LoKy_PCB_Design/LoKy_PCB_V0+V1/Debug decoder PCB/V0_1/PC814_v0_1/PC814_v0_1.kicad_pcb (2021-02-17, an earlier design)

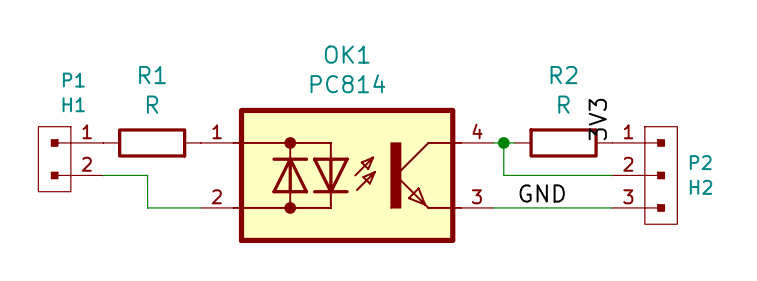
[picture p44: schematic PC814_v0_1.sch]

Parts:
OK1: PC814; DIL04
P1: H1; HEADER_M_2.54MM_1R2P_ST_AU_PTH
P2: H2; HEADER_M_2.54MM_1R3P_ST_AU_PTH
R1, R2: R; R_Axial_DIN0207_L6.3mm_D2.5mm_P10.16mm_Horizontal

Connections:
/3V3: P2.1, R2.1
/GND: OK1.3, P2.3
unnamed: OK1.1, R1.2
unnamed: OK1.2, P1.2
unnamed: OK1.4, P2.2, R2.2
unnamed: P1.1, R1.1

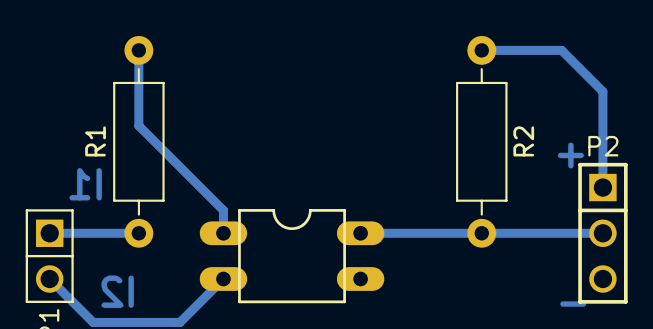
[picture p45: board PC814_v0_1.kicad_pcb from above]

Board: 2 copper layers, 5 parts (0 on the bottom side), 6 nets.

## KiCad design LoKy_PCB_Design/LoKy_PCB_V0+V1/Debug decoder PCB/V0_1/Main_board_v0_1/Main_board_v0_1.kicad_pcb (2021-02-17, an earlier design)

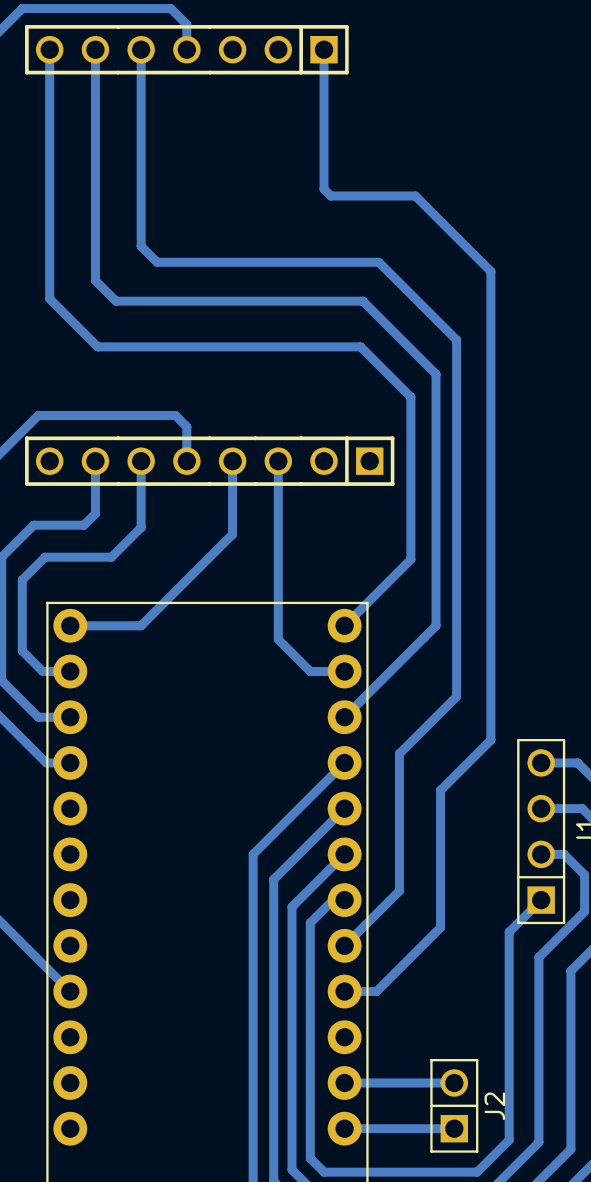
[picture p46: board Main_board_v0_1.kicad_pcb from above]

Board: 2 copper layers, 5 parts (0 on the bottom side), 17 nets.

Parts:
J1: H1; HEADER_F_2.54MM_1R4P_ST_SN_PTH
J2: H2; HEADER_F_2.54MM_1R2P_ST_AU_PTH
P1: H1; HEADER_M_2.54MM_1R7P_ST_AU_PTH
P2: H2; HEADER_M_2.54MM_1R8P_ST_AU_PTH
U1: ARDUINO_PRO_MINI; MODULE_ARDUINO_PRO_MINI

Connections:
/3V3: P1.4, U1.JP6_4
/DIO0: P1.5, U1.JP7_8
/DIO1: P1.6, U1.JP7_3
/DIO2: P1.7, U1.JP7_1
/GND: P1.1, U1.JP7_9
/MISO: P2.7, U1.JP6_10
/MOSI: P2.6, U1.JP6_11
/NSS: P2.4, U1.JP6_12
/RST: P2.3, U1.JP7_2
/SCK: P2.5, U1.JP6_9
unnamed: J1.1, U1.JP7_7
unnamed: J1.2, U1.JP7_6
unnamed: J1.3, U1.JP7_5
unnamed: J1.4, U1.JP7_4
unnamed: J2.1, U1.JP7_12
unnamed: J2.2, U1.JP7_11
unnamed: U1.JP1_5, U1.JP1_6

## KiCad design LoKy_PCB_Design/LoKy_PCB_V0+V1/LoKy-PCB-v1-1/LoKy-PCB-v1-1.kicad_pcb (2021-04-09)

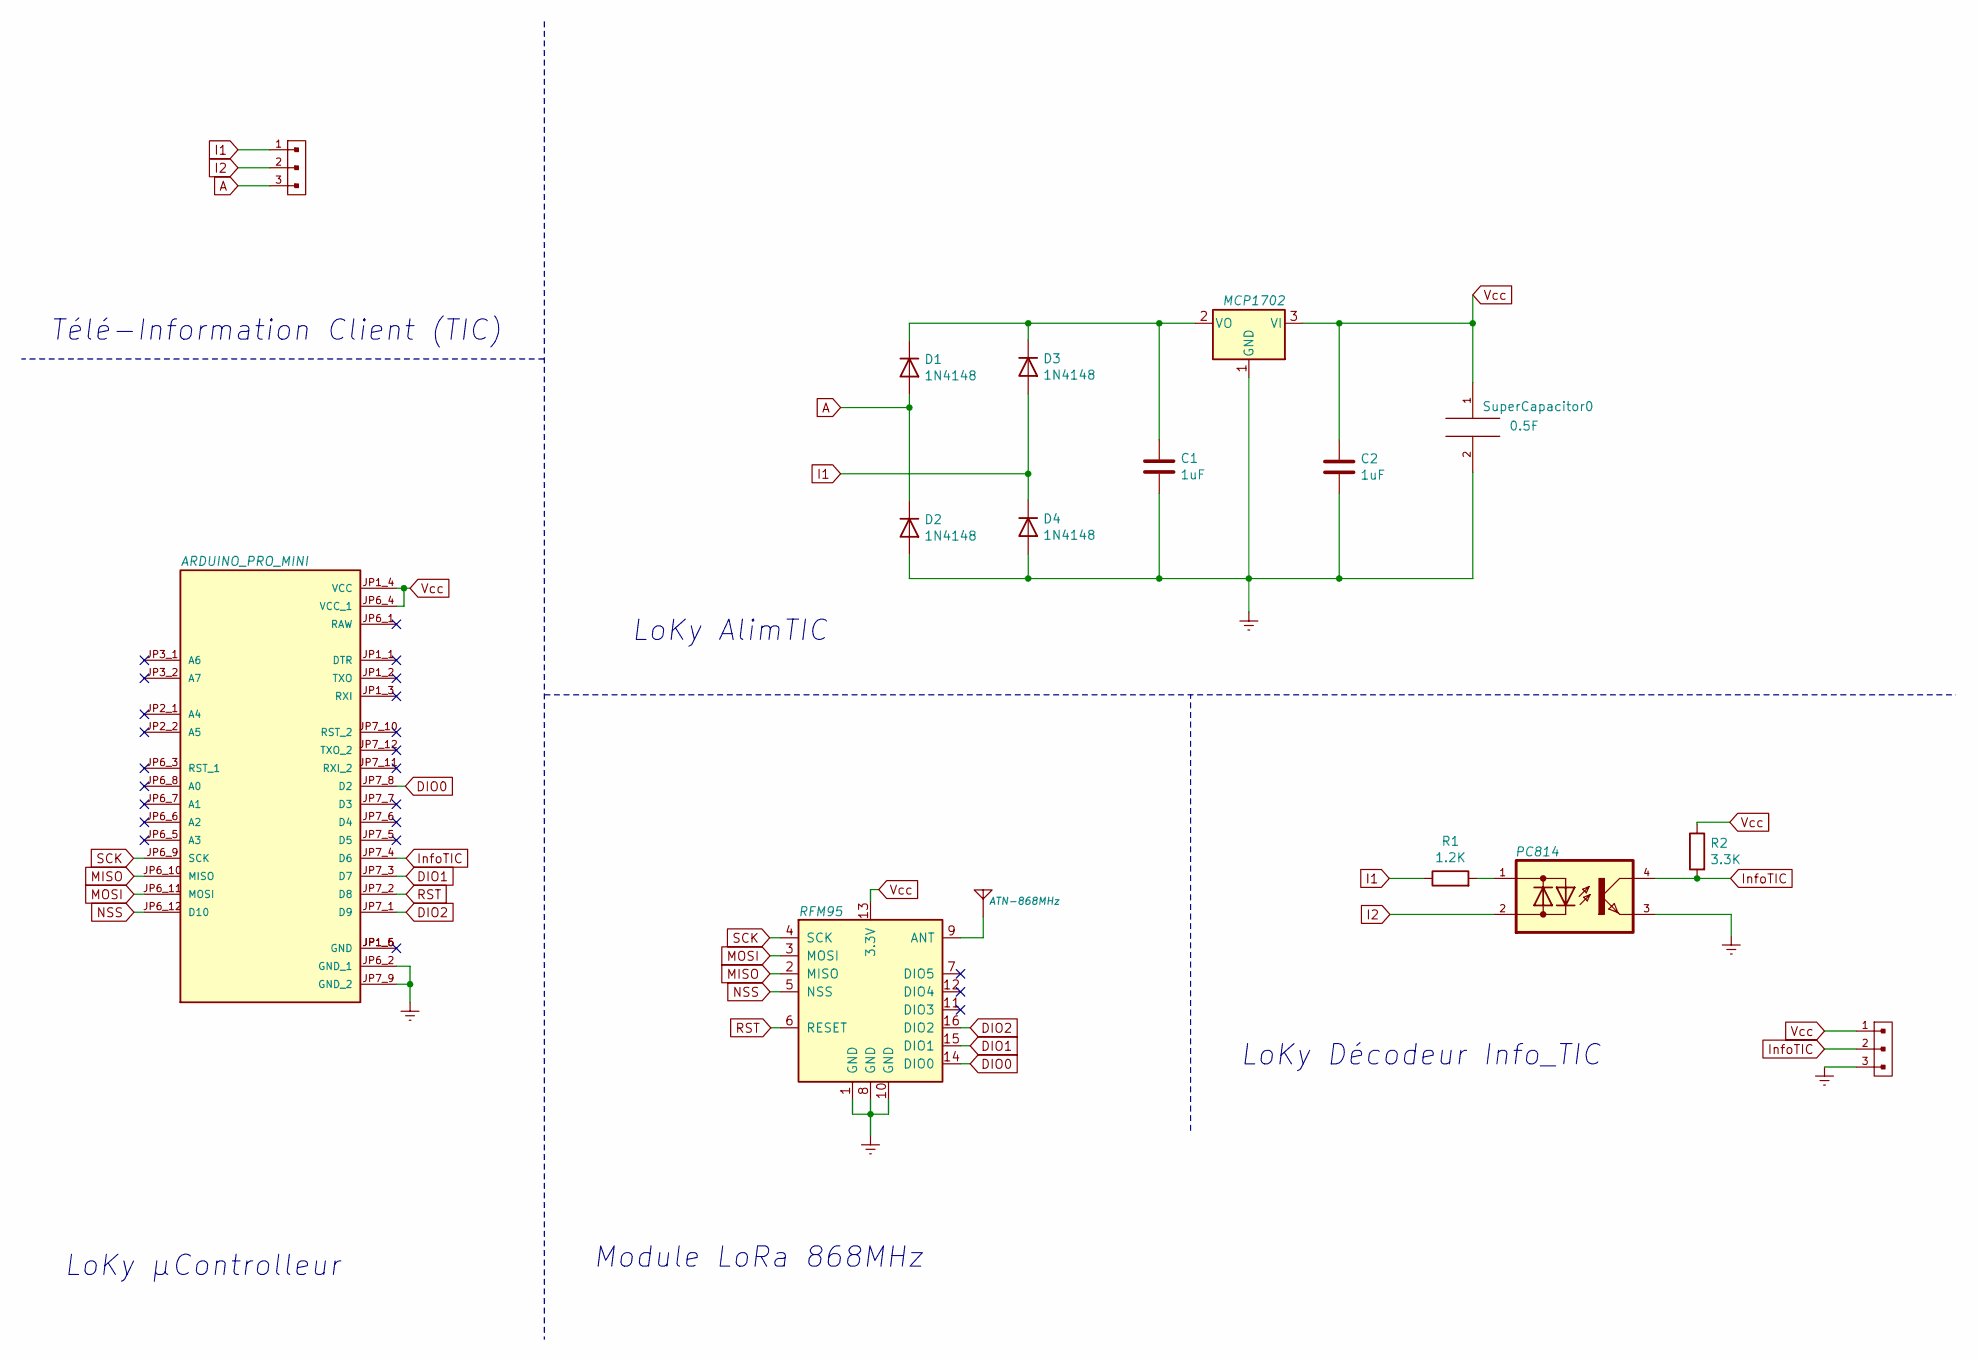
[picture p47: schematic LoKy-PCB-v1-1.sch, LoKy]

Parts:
ATN1: ATN-868MHz
C1, C2: 1uF; C_Rect_L7.2mm_W5.5mm_P5.00mm_FKS2_FKP2_MKS2_MKP2
D1, D2, D3, D4: 1N4148; D_DO-35_SOD27_P7.62mm_Horizontal
MCP1702: MCP1702; TO-92_HandSolder
Opto1: PC814; DIL04
P1: HEADER_M_2.54MM_1R3P_ST_AU_PTH; PinHeader_1x03_P2.54mm_Horizontal
P2: HEADER_M_2.54MM_1R3P_ST_AU_PTH; PinHeader_1x03_P2.54mm_Vertical
R1: 1.2K; R_Axial_DIN0309_L9.0mm_D3.2mm_P12.70mm_Horizontal
R2: 3.3K; R_Axial_DIN0309_L9.0mm_D3.2mm_P12.70mm_Horizontal
SuperCapacitor0: 0.5F; C_Rect_L19.0mm_W9.0mm_P15.00mm_MKS4
U1: RFM95; HOPERF_RFM9XW_SMD
U2: ARDUINO_PRO_MINI; MODULE_ARDUINO_PRO_MINI; PARTREV N/A

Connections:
A: D1.2 (A), D2.1 (K), P1.3
DIO0: U1.14 (DIO0), U2.JP7_8 (D2)
DIO1: U1.15 (DIO1), U2.JP7_3 (D7)
DIO2: U1.16 (DIO2), U2.JP7_1 (D9)
GNDREF: C1.2, C2.2, D2.2 (A), D4.2 (A), MCP1702.1 (GND), Opto1.3, P2.3, SuperCapacitor0.2, U1.1 (GND), U1.8 (GND), U1.10 (GND), U2.JP6_2 (GND_1), U2.JP7_9 (GND_2)
I1: D3.2 (A), D4.1 (K), P1.1, R1.1
I2: Opto1.2, P1.2
InfoTIC: Opto1.4, P2.2, R2.2, U2.JP7_4 (D6)
MISO: U1.2 (MISO), U2.JP6_10 (MISO)
MOSI: U1.3 (MOSI), U2.JP6_11 (MOSI)
NSS: U1.5 (NSS), U2.JP6_12 (D10)
unnamed: ATN1.1, U1.9 (ANT)
unnamed: C1.1, D1.1 (K), D3.1 (K), MCP1702.2 (VO)
unnamed: Opto1.1, R1.2
unnamed: U2.JP1_5 (GND), U2.JP1_6 (GND)
RST: U1.6 (RESET), U2.JP7_2 (D8)
SCK: U1.4 (SCK), U2.JP6_9 (SCK)
Vcc: C2.1, MCP1702.3 (VI), P2.1, R2.1, SuperCapacitor0.1, U1.13 (3.3V), U2.JP1_4 (VCC), U2.JP6_4 (VCC_1)

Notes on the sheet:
LoKy μControlleur
Module LoRa 868MHz
LoKy AlimTIC
LoKy Décodeur Info_TIC
Télé-Information Client (TIC)

Board: 2 copper layers, 15 parts (0 on the bottom side), 17 nets, no tracks yet.

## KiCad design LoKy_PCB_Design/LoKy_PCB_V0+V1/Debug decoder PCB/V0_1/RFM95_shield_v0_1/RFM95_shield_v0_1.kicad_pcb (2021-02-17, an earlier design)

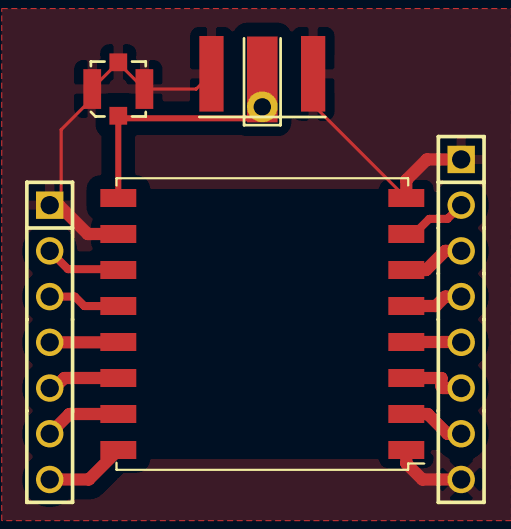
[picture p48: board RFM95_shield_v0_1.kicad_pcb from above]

Board: 2 copper layers, 6 parts (0 on the bottom side), 13 nets.

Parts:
AE1: Antenna_Helical_RA; ANTENNA_HELICAL_RA
J1: u.FL; U.FL-R-SMT
J2: SMA; SMA_EDGE
P1: H1; HEADER_M_2.54MM_1R7P_ST_AU_PTH
P2: H2; HEADER_M_2.54MM_1R8P_ST_AU_PTH
U1: RFM95; HOPERF_RFM9XW_SMD

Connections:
/3V3: P1.4, U1.13
/DIO0: P1.5, U1.14
/DIO1: P1.6, U1.15
/DIO2: P1.7, U1.16
/GND: J1.2, J1.3, J1.4, J2.2, J2.3, P1.1, P2.1, P2.8, U1.1, U1.8, U1.10
/MISO: P2.7, U1.2
/MOSI: P2.6, U1.3
/NSS: P2.4, U1.5
/RST: P2.3, U1.6
/SCK: P2.5, U1.4
unnamed: P1.2, U1.11
unnamed: P1.3, U1.12
unnamed: P2.2, U1.7

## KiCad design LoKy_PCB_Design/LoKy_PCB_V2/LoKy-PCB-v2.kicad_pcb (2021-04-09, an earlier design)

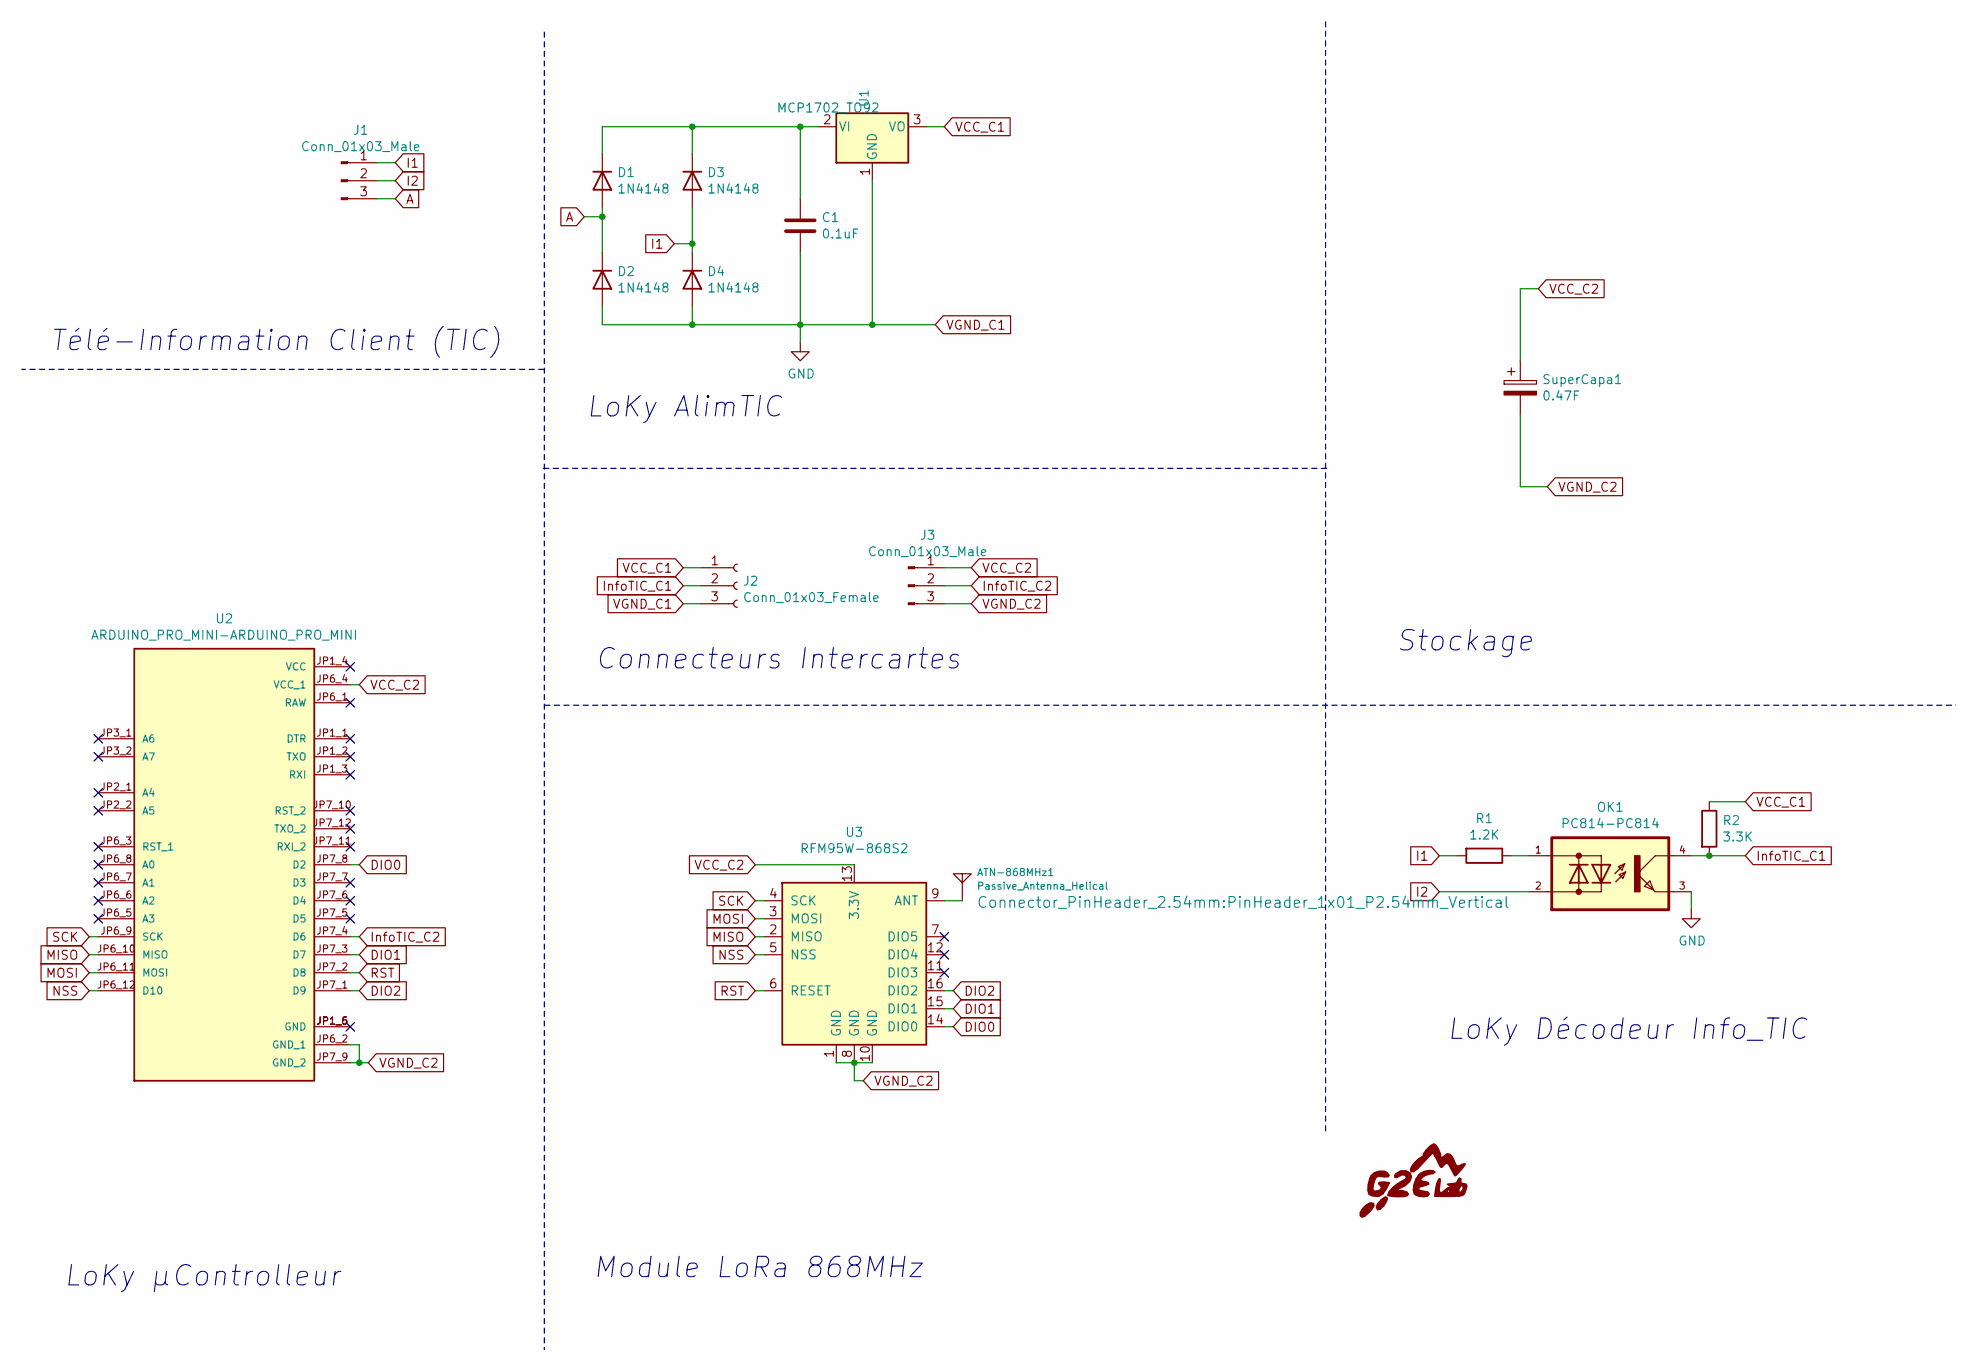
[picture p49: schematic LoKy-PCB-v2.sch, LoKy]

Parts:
ATN-868MHz1: Passive_Antenna_Helical; PinHeader_1x01_P2.54mm_Vertical
C1: 0.1uF; C_Rect_L7.0mm_W2.5mm_P5.00mm
D1, D2, D3, D4: 1N4148; D_DO-35_SOD27_P7.62mm_Horizontal
J1: Conn_01x03_Male; Connecteur_Linky
J2: Conn_01x03_Female; PinHeader_1x03_P2.54mm_Vertical
J3: Conn_01x03_Male; PinHeader_1x03_P2.54mm_Vertical
OK1: PC814-PC814; DIL04
R1: 1.2K; R_Axial_DIN0207_L6.3mm_D2.5mm_P7.62mm_Horizontal
R2: 3.3K; R_Axial_DIN0207_L6.3mm_D2.5mm_P7.62mm_Horizontal
SuperCapa1: 0.47F; SuperCapa
U1: MCP1702_TO92; TO-92_Inline
U2: ARDUINO_PRO_MINI-ARDUINO_PRO_MINI; ArduProMini_minimalist; PARTREV N/A
U3: RFM95W-868S2; HOPERF_RFM9XW_SMD

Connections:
A: D1.2 (A), D2.1 (K), J1.3
DIO0: U2.JP7_8 (D2), U3.14 (DIO0)
DIO1: U2.JP7_3 (D7), U3.15 (DIO1)
DIO2: U2.JP7_1 (D9), U3.16 (DIO2)
I1: D3.2 (A), D4.1 (K), J1.1, R1.2
I2: J1.2, OK1.2
InfoTIC_C1: J2.2, OK1.4, R2.2
InfoTIC_C2: J3.2, U2.JP7_4 (D6)
MISO: U2.JP6_10 (MISO), U3.2 (MISO)
MOSI: U2.JP6_11 (MOSI), U3.3 (MOSI)
NSS: U2.JP6_12 (D10), U3.5 (NSS)
unnamed: ATN-868MHz1.1, U3.9 (ANT)
unnamed: C1.1, D1.1 (K), D3.1 (K), U1.2 (VI)
unnamed: OK1.1, R1.1
unnamed: U2.JP1_5 (GND), U2.JP1_6 (GND)
RST: U2.JP7_2 (D8), U3.6 (RESET)
SCK: U2.JP6_9 (SCK), U3.4 (SCK)
VCC_C1: J2.1, R2.1, U1.3 (VO)
VCC_C2: J3.1, SuperCapa1.1, U2.JP6_4 (VCC_1), U3.13 (3.3V)
VGND_C1: C1.2, D2.2 (A), D4.2 (A), J2.3, OK1.3, U1.1 (GND)
VGND_C2: J3.3, SuperCapa1.2, U2.JP6_2 (GND_1), U2.JP7_9 (GND_2), U3.1 (GND), U3.8 (GND), U3.10 (GND)

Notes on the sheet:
LoKy μControlleur
Module LoRa 868MHz
LoKy AlimTIC
LoKy Décodeur Info_TIC
Télé-Information Client (TIC)
Connecteurs Intercartes
Stockage

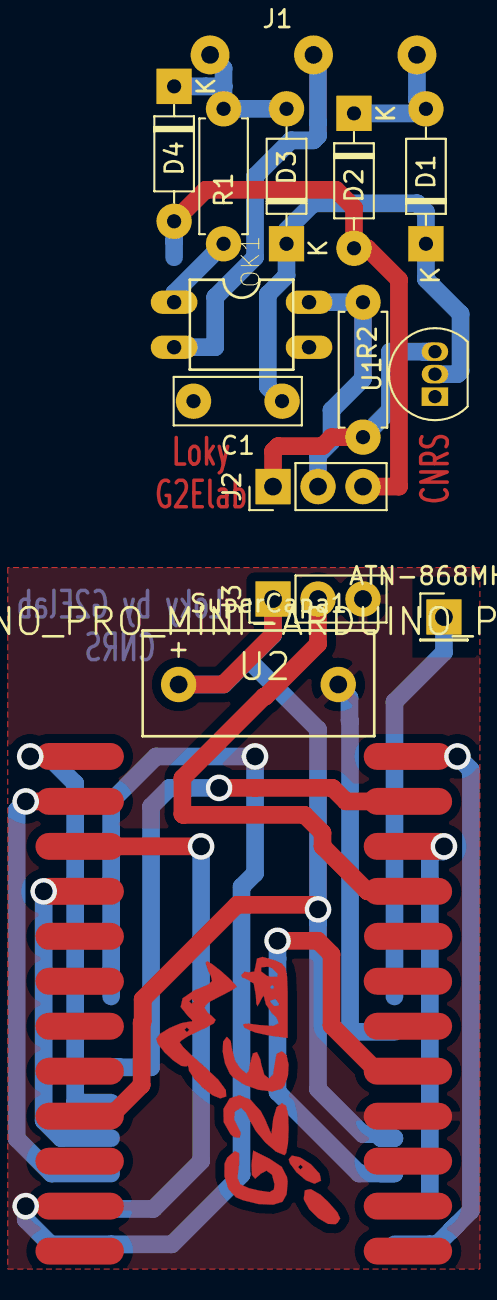
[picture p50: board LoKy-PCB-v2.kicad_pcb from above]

Board: 2 copper layers, 16 parts (1 on the bottom side), 21 nets.

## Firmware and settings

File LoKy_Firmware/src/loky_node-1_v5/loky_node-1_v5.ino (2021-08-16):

#include <lmic.h>
#include <hal/hal.h>
#include <SPI.h>
#include "Device_Keys.h"
#include <SoftwareSerial.h>
SoftwareSerial* LoKyTIC;

// Schedule the transmission every 
unsigned int TX_INTERVAL = 90; //seconds

// Set duration to reset LoKy  
#define T_LoKy_reset 6 //in hour(s)

static osjob_t sendjob;
static float VccTIC;
char HHPHC;
int ISOUSC;               // intensité souscrite  
int IINST;                // intensité instantanée    en A
int PAPP;                 // puissance apparente      en VA
unsigned long HCHC;       // compteur Heures Creuses  en W
unsigned long HCHP;       // compteur Heures Pleines  en W
unsigned long BASE;       // index BASE               en W
String PTEC;              // période tarif en cours
String ADCO;              // adresse du compteur
String OPTARIF;           // option tarifaire
int IMAX;                 // intensité maxi = 90A
String MOTDETAT;          // status word
boolean teleInfoReceived;

char chksum(char *buff, uint8_t len);
boolean handleBuffer(char *bufferTeleinfo, int sequenceNumnber);

void(* resetFunc) (void) = 0; //declare reset function at address 0 - MUST BE ABOVE LOOP

// ---------------------------------------------- //
//      Read the Voltage regulated from TIC       //
long readVcc() {
  long result;
  // Read 1.1V reference against AVcc
  ADMUX = _BV(REFS0) | _BV(MUX3) | _BV(MUX2) | _BV(MUX1);
  delay(2); // Wait for Vref to settle
  ADCSRA |= _BV(ADSC); // Convert
  while (bit_is_set(ADCSRA, ADSC));
  result = ADCL;
  result |= ADCH << 8;
  result = 1126400L / result;
  return result; // Return Vcc in mV
}
// ---------------------------------------------- //

// ---------------------------------------------- //
//   Update new values from TIC for the next TX   //
void updateParameters() {
  VccTIC = (int)(readVcc()); // returns VccTIC in mVolt for LoKy decoder
//  Serial.print("VccTIC = "); Serial.print(VccTIC/1000); Serial.println(" V");
  LoKyTIC->begin(1200);  // Important!!! -> RESTART LoKyTIC 
  teleInfoReceived = readTeleInfo();
  LoKyTIC->end(); // Important!!! -> STOP LoKyTIC to send packet.
}
// ---------------------------------------------- //

// ---------------------------------------------- //
//              LoRaWAN events (LMiC)
void onEvent (ev_t ev) {
  Serial.print(os_getTime()); Serial.print(": ");
  //Reset every T_LoKy_reset hours
      if (millis() >= (T_LoKy_reset*3600000)) resetFunc();
  switch (ev) {
    case EV_SCAN_TIMEOUT:
      Serial.println(F("EV_SCAN_TIMEOUT"));
      break;
    case EV_BEACON_FOUND:
      Serial.println(F("EV_BEACON_FOUND"));
      break;
    case EV_BEACON_MISSED:
      Serial.println(F("EV_BEACON_MISSED"));
      break;
    case EV_BEACON_TRACKED:
      Serial.println(F("EV_BEACON_TRACKED"));
      break;
    case EV_JOINING:
      Serial.println(F("EV_JOINING"));
      break;      
    case EV_JOINED:
      Serial.println(F("EV_JOINED"));
      LMIC_setLinkCheckMode(0);
      break;
    case EV_JOIN_FAILED:
      Serial.println(F("EV_JOIN_FAILED"));
      LMiC_Startup(); //Reset LMIC and retry
      break;
    case EV_REJOIN_FAILED:
      Serial.println(F("EV_REJOIN_FAILED"));
      LMiC_Startup(); //Reset LMIC and retry
      break;
      
    case EV_TXCOMPLETE:
      Serial.println(F("EV_TXCOMPLETE"));
      if (LMIC.txrxFlags & TXRX_ACK) Serial.println(F("Received ack"));
      if (LMIC.dataLen) { Serial.print(F("Received ")); Serial.print(LMIC.dataLen); Serial.println(F(" bytes.")); }
      delay(50);
//      setDataRate(); // Use for ADR

      // Schedule next transmission
      do_sleep(TX_INTERVAL);
      os_setTimedCallback(&sendjob, os_getTime() + ms2osticks(TX_INTERVAL*1000), do_send);
      break;
       
    case EV_LOST_TSYNC:
      Serial.println(F("EV_LOST_TSYNC"));
      break;
    case EV_RESET:
      Serial.println(F("EV_RESET"));
      break;
    case EV_RXCOMPLETE:
      Serial.println(F("EV_RXCOMPLETE"));
      break;
    case EV_LINK_DEAD:
      Serial.println(F("EV_LINK_DEAD"));
      break;
    case EV_LINK_ALIVE:
      Serial.println(F("EV_LINK_ALIVE"));
      break;
      
    default:
      Serial.print(F("Unknown event: "));
      Serial.println((unsigned) ev);
      break;
  }
}
// ---------------------------------------------- //

// ---------------------------------------------- //
//              Verify LoKy Payload               //
void check_newValues() {
  Serial.println("");
  Serial.println("-----");
  Serial.println(" * Verify new payload ");
  unsigned long HP_pre = HCHP;
  unsigned long HC_pre = HCHC;
  unsigned long BA_pre = BASE;
  
  updateParameters();
  
  while (((HCHP <= HP_pre) && (HCHC<=HC_pre) && (BASE <= BA_pre)) || ADCO == 000000000000){
    LoKyTIC->end();
    Serial.println(" * LoKyTIC frame updating...");
    updateParameters();  continue;
  }
/*
  while (BASE < BA_pre || ADCO == 000000000000){
    LoKyTIC->end();
    Serial.println(" * LoKyTIC BASE frame updating...");
    updateParameters();  continue;
  }
*/  
  Serial.println("==> Finished checking, display info:");

  if (teleInfoReceived) { displayTeleInfo();}
}
// ---------------------------------------------- //

// ---------------------------------------------- //
//      Send the encrypted LoKy packet to TTN     //
void do_send(osjob_t* j) {
  // Check if there is not a current TX/RX job running
  if (LMIC.opmode & OP_TXRXPEND) {Serial.println(F("OP_TXRXPEND, not sending"));}
  else {
    check_newValues();
    
    int vc = VccTIC;    
    uint8_t is = IINST;
    uint16_t pa = PAPP;
    
    unsigned char loky_data[25];
    uint32_t hc = HCHC;
    uint32_t hp = HCHP;
    uint32_t be = BASE;

    // LoKy payload arrangement for sending to TTN
//    loky_data[0] = 0x0;         //data_type = 0 --> VccTIC   (2 bytes)
//    loky_data[1] = vc >> 8;
//    loky_data[2] = vc & 0xFF;
    loky_data[0] = 0x7;         //data_type = 7 --> IINST    (2 bytes)
    loky_data[1] = is >> 8;
    loky_data[2] = is & 0xFF;
    loky_data[3] = 0x9;         //data_type = 9 --> PAPP     (3 bytes)
    loky_data[4] = pa >> 16;
    loky_data[5] = pa >> 8;
    loky_data[6] = pa & 0xFF; 
    loky_data[7] = 0x04;       //data_type = 4 --> HCHP     (5 bytes)
    loky_data[8] = hc >> 32;
    loky_data[9] = hc >> 24;
    loky_data[10] = hc >> 16;
    loky_data[11] = hc >> 8;
    loky_data[12] = hc & 0xFF;
    loky_data[13]  = 0x5;       //data_type = 5 --> HCHC     (5 bytes)
    loky_data[14] = hp >> 32;
    loky_data[15] = hp >> 24;
    loky_data[16] = hp >> 16;
    loky_data[17] = hp >> 8;
    loky_data[18] = hp & 0xFF;  
    loky_data[19] = 0x08;       //data_type = 8 --> BASE     (5 bytes)
    loky_data[20] = be >> 32;
    loky_data[21] = be >> 24;
    loky_data[22] = be >> 16;
    loky_data[23] = be >> 8;
    loky_data[24] = be & 0xFF;
    LMIC_setTxData2(1, loky_data, sizeof(loky_data), 0);
    Serial.println(F("LoKy packet queued!!!"));
    
    LoKyTIC->end(); // Important!!! -> STOP LoKyTIC to send packet.
  }
  // Next TX is scheduled after TX_COMPLETE event.
}
// ---------------------------------------------- //

// ---------------------------------------------- //
//        Basic constructor for LoKyTIC           //
void TeleInfo() {const uint8_t LoKy_Rx = 6;
const uint8_t LoKy_Tx = 3; 
// LoKy_Tx is NOT used but reserved !!! (could be connected to GND)  
  LoKyTIC = new SoftwareSerial(LoKy_Rx, LoKy_Tx);
  // variables initializations
  ADCO = "000000000000";
  OPTARIF = "----";
  ISOUSC = 0;
  HCHC = 0L;
  HCHP = 0L;
  BASE = 0L;
  PTEC = "----";
  HHPHC = '-';
  IINST = 0;
  IMAX = 0;
  PAPP = 0;
  MOTDETAT = "------";
}
// ---------------------------------------------- //

// ---------------------------------------------- //
//           TIC frame capture from Linky         //
boolean readTeleInfo()  {
//boolean readTeleInfo(bool TIC_state)  {
#define startFrame  0x02
#define endFrame    0x03
#define startLine   0x0A
#define endLine     0x0D
#define maxFrameLen 280

  int comptChar=0;  // variable de comptage des caractères reçus 
  char charIn=0;    // variable de mémorisation du caractère courant en réception
  char bufferTeleinfo[21] = "";
  int bufferLen = 0;
  int checkSum;
  int sequenceNumnber = 0;    // number of information group

  //--- wait for starting frame character 
  while (charIn != startFrame)
  { // "Start Text" STX (002 h) is the beginning of the frame
    if (LoKyTIC->available())
     charIn = LoKyTIC->read()& 0x7F; // Serial.read() vide buffer au fur et à mesure
  } // fin while (tant que) pas caractère 0x02
  //--- wait for the ending frame character 
  while (charIn != endFrame)
  { // tant que des octets sont disponibles en lecture : on lit les caractères
    if (LoKyTIC->available()) {
      charIn = LoKyTIC->read()& 0x7F;
      // incrémente le compteur de caractère reçus
      comptChar++;
      if (charIn == startLine)  bufferLen = 0;
      bufferTeleinfo[bufferLen] = charIn;
      // on utilise une limite max pour éviter String trop long en cas erreur réception
      // ajoute le caractère reçu au String pour les N premiers caractères
      if (charIn == endLine)  {
        checkSum = bufferTeleinfo[bufferLen -1];
        if (chksum(bufferTeleinfo, bufferLen) == checkSum)  {// we clear the 1st character
          strncpy(&bufferTeleinfo[0], &bufferTeleinfo[1], bufferLen -3);
          bufferTeleinfo[bufferLen -3] = 0x00;
          sequenceNumnber++;
          if (! handleBuffer(bufferTeleinfo, sequenceNumnber))  {
            Serial.println(F("Sequence error ..."));
            return false;
          }
        }
        else  {
          Serial.println(F("Checksum error!"));
          return false;
        }
      }
      else 
        bufferLen++;
    }
    if (comptChar > maxFrameLen)  {
      Serial.println(F("Overflow error ..."));
      return false;
    }
  }
  return true;
}
// ---------------------------------------------- //

// ---------------------------------------------- //
//               TIC frame parsing                //
boolean handleBuffer(char *bufferTeleinfo, int sequenceNumnber) {
  // create a pointer to the first char after the space
  char* resultString = strchr(bufferTeleinfo,' ') + 1;
  boolean sequenceIsOK;

  switch(sequenceNumnber) {
    
  case 1:
    if (sequenceIsOK = bufferTeleinfo[0]=='A')  ADCO = String(resultString);
    break;
  case 2:
    if (sequenceIsOK = bufferTeleinfo[0]=='O')  OPTARIF = String(resultString);
    break;
  case 3:
    if (sequenceIsOK = bufferTeleinfo[1]=='S')  ISOUSC = atol(resultString);
    break;

  case 4:
    if (sequenceIsOK = bufferTeleinfo[3]=='C'){ 
      #define Linky_HCHP true
        #ifdef Linky_HCHP
        HCHC = atol(resultString);
        #endif
    }
    else if (sequenceIsOK = bufferTeleinfo[0]=='B') { 
      #define Linky_BASE true
        #ifdef Linky_BASE
        BASE = atol(resultString);
        #endif

    }
    break;

  case 5:
    if (sequenceIsOK = bufferTeleinfo[3]=='P'){ 
      #define Linky_HCHP true
        #ifdef Linky_HCHP
        HCHP = atol(resultString);
        #endif
    }
    else if (sequenceIsOK = bufferTeleinfo[1]=='T') { 
      #define Linky_BASE true
        #ifdef Linky_BASE
        PTEC = String(resultString);
        #endif
    }
    break;

  case 6:
    if (sequenceIsOK = bufferTeleinfo[1]=='T'){ 
      #define Linky_HCHP true
        #ifdef Linky_HCHP
        PTEC = String(resultString);
        #endif
        }
    else if (sequenceIsOK = bufferTeleinfo[1]=='I') { 
      #define Linky_BASE true
        #ifdef Linky_BASE
        IINST = atol(resultString);
        #endif
        }
    break;
        
  case 7:
    if (sequenceIsOK = bufferTeleinfo[1]=='I'){ 
      #define Linky_HCHP true
        #ifdef Linky_HCHP
        IINST =atol(resultString);
        #endif
        }
    else if (sequenceIsOK = bufferTeleinfo[1]=='M') { 
      #define Linky_BASE true
        #ifdef Linky_BASE
        IMAX =atol(resultString);
        #endif
        }
    break;

  case 8:
    if (sequenceIsOK = bufferTeleinfo[1]=='M') {
      #define Linky_HCHP true
        #ifdef Linky_HCHP
        IMAX =atol(resultString);
        #endif
        }
    else if (sequenceIsOK = bufferTeleinfo[1]=='A') { 
      #define Linky_BASE true
        #ifdef Linky_BASE
        PAPP =atol(resultString);
        #endif
        }
    break;
        
  case 9:
    if (sequenceIsOK = bufferTeleinfo[1]=='A') {
      #define Linky_HCHP true
        #ifdef Linky_HCHP
        PAPP =atol(resultString);
        #endif
        }
    else if (sequenceIsOK = bufferTeleinfo[1]=='H') {
      #define Linky_BASE true
        #ifdef Linky_BASE
        HHPHC = resultString[0];
        #endif
        }
    break;

  case 10:
    if (sequenceIsOK = bufferTeleinfo[1]=='H') { 
      #define Linky_HCHP true
        #ifdef Linky_HCHP
        HHPHC = resultString[0];
        #endif
        }
    else if (sequenceIsOK = bufferTeleinfo[1]=='O') { 
      #define Linky_BASE true
        #ifdef Linky_BASE
        MOTDETAT = String(resultString);
        #endif
        }
    break;
        
  case 11:
    if (sequenceIsOK = bufferTeleinfo[1]=='O')  MOTDETAT = String(resultString);
    break;

  }
    if(!sequenceIsOK) {
      Serial.print(F("Out of sequence ..."));
      Serial.println(bufferTeleinfo);
    }
  return sequenceIsOK;
}
// ---------------------------------------------- //

// ---------------------------------------------- //
//            Checksum Calculation                //
char chksum(char *buff, uint8_t len)  {
  int i;
  char sum = 0;
  for (i=1; i<(len-2); i++) 
    sum = sum + buff[i];
  sum = (sum & 0x3F) + 0x20;
  return(sum);
}
// ---------------------------------------------- //

// ---------------------------------------------- //
//          Print TIC frame from Linky            //
void displayTeleInfo()  {  
//  Serial.print(F("ADCO ")); Serial.println(ADCO);
  Serial.print(F("OPTARIF "));  Serial.println(OPTARIF);
//  Serial.print(F("ISOUSC ")); Serial.println(ISOUSC);
  Serial.print(F("HCHC ")); Serial.println(HCHC);
  Serial.print(F("HCHP ")); Serial.println(HCHP);
  Serial.print(F("BASE ")); Serial.println(BASE);
  Serial.print(F("PTEC ")); Serial.println(PTEC);
  Serial.print(F("IINST "));Serial.println(IINST);
//  Serial.print(F("IMAX ")); Serial.println(IMAX);
  Serial.print(F("PAPP ")); Serial.println(PAPP);
//  Serial.print(F("HHPHC ")); Serial.println(HHPHC);
//  Serial.print(F("MOTDETAT ")); Serial.println(MOTDETAT);   
}
// ---------------------------------------------- //

// ---------------------------------------------- //
//      Called from setup to activate LoKy        //
void LMiC_Startup() {
  os_init();
  // Reset the MAC state.
  LMIC_reset(); LMIC_setLinkCheckMode(1); LMIC_setAdrMode(1);  
  // Increase window time for clock accuracy problem
  LMIC_setClockError(MAX_CLOCK_ERROR * 1 / 100);
  // Join the network, sending will be started after the event "Joined"
  LMIC_startJoining();
}
// ---------------------------------------------- //

// ---------------------------------------------- //
//                   LoKy setup                   //
void setup() {
  Serial.begin(9600);
  TeleInfo();    // LoKyTIC init
  Serial.println("");
  Serial.println("*-_______________________________-*");
  Serial.println(F("      .::LoKy (re)starting::."        ));
  delay(100);
//  Check_SupCapa();
  LMiC_Startup();       // LMiC init
  do_send(&sendjob);    // OTAA start
}
// ---------------------------------------------- //

//*     .::Fixed LOOP - Do NOT interfered::.     *//
void loop() {
  os_runloop_once();
  }

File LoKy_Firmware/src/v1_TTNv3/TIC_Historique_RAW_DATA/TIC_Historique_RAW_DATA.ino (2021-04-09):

#include <SoftwareSerial.h>

const uint8_t LoKy_RX = 6;
const uint8_t LoKy_TX = 3;

SoftwareSerial LoKyTIC(LoKy_RX, LoKy_TX);

void setup() {

//  pinMode(7, OUTPUT);
//  pinMode(5, OUTPUT);
  LoKyTIC.begin(1200);
  Serial.begin(9600);
  Serial.println("LoKy starting...");
  delay(50);
}

void loop() {
  
//  digitalWrite(7, HIGH);
//  digitalWrite(5, LOW);

  while (LoKyTIC.available()) {
    // read the incoming character
    char inChar = (char)LoKyTIC.read() & 0x7F;
    Serial.print(inChar);
    }
}

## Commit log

2021-02-03 Upload KiCad design v1
    [GeeLink_v1.kicad_pcb, GeeLink_v1.sch]
2021-02-09 Publish PCB design for LoKy decoder v0.1
    [PC814.step, PCB_Decoder_v0.kicad_pcb, PCB_Decoder_v0.sch]
2021-02-10 Update new design
    [ProMini+opto.kicad_pcb, ProMini+opto.sch, RFM95_platine.kicad_pcb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]
2021-02-11 Separate each element
    [Main_board_v0_1.kicad_pcb, Main_board_v0_1.sch, PC814.kicad_pcb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]
2021-02-17 PCB decoder v0 update
    [PC814.kicad_pcb]
2021-02-17 Update 17/02/2021
    [GeeLink_v1.kicad_pcb, GeeLink_v1.sch, Main_board_v0_1.kicad_pcb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]
2021-02-20 Update LoKy Decoder v0.2
    [Main_board_v0_1.kicad_pcb, Main_board_v0_1.sch, Main_board_v0_2.kicad_pcb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]
2021-02-20 Update Decoder v0.2
    [Main_board_v0_2.kicad_pcb]
2021-03-28 Add files via upload
    Modification of Dimensions
    [Loky_corps.STL, Loky_couvercle.STL]
2021-04-01 Update PCB version 1
    [LoKy-PCB-v1-1.kicad_pcb, LoKy-PCB-v1-1.sch, LoKy-PCB-v1-1a.kicad_pcb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]
2021-04-02 Update KiCAD library
    [LoKy-PCB-v1-1a.kicad_pcb, PC814.step]
2021-04-09 Update the PCB to revision 2
    [LoKy-PCB-v2.kicad_pcb, LoKy-PCB-v2.sch]
2021-04-09 Clean of repository
    [LoKy-PCB-v1-1.kicad_pcb, LoKy-PCB-v1-1.sch, LoKy-PCB-v1-1a.kicad_pcb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]
2021-04-09 Move folder LoKy-PCB-v2.pretty
2021-04-09 Reamenagement of folder to main items (Code,PCB,Documentation,STL)
    [LoKy-PCB-v1-1.kicad_pcb, LoKy-PCB-v1-1.sch, LoKy-PCB-v1-1a.kicad_pcb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]
2021-04-09 Modification of naming to LoKy
    [Loky_corps.STL, Loky_couvercle.STL]
2021-04-09 Update Tutorial + Folder Name modification
    [LoKy-PCB-v1-1.kicad_pcb, LoKy-PCB-v1-1.sch, LoKy-PCB-v1-1a.kicad_pcb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]
2021-06-07 Update LoKy v2 - Auto reset
    [1_TIC_decoder.ino, 2_TIC_decoder.ino, TIC_Historique_RAW_DATA.ino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]
2021-06-08 V2 du boitier
    V2 du boitier
    [Loky_corps.STL, Loky_couvercle.STL]
2021-06-08 Ajout bouton reset
    [Loky_corps.STL]
2021-06-08 Reorientation corps pour impression directe
    [Loky_corps.STL]
2021-06-08 Correction lettre sur couvercle pour impression 3D
    Correction lettre sur couvercle pour impression 3D
    [Loky_couvercle.STL]
2021-06-09 V3 du boitier
    Ajout d'un passe fil pour permettre l'ajout d'un autre capteur en parallèle
    [Loky_corps.STL, Loky_couvercle.STL]
2021-06-13 V3
    Modification to hold board
    [Loky_corps.STL, Loky_couvercle.STL]
2021-07-13 Update Test 7 LoKys
    [LoKy_PCB_v3.kicad_pcb, LoKy_PCB_v3.sch]
2021-07-20 V4
    V4
    [Loky_corps.STEP, Loky_corps.STL, Loky_couvercle.STEP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]
2021-07-21 Correction of HCHP/BASE option
    Correction of HCHP/BASE option
    [loky_node-1_v2-2.ino]

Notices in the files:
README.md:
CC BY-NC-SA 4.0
